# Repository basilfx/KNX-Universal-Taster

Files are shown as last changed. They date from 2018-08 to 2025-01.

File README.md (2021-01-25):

# KNX Universal Taster
DIY universal taster interface for the KNX bus.

## Introduction
This repository contains my designs for creating a custom KNX universal taster
interface (or actor). This is board that can be used for several purposes, but
its main purpose is to convert pulse-based wall switches into KNX-enabled
switches. The boards are designed to be small and should fit wall boxes with a
depth of 50 mm.

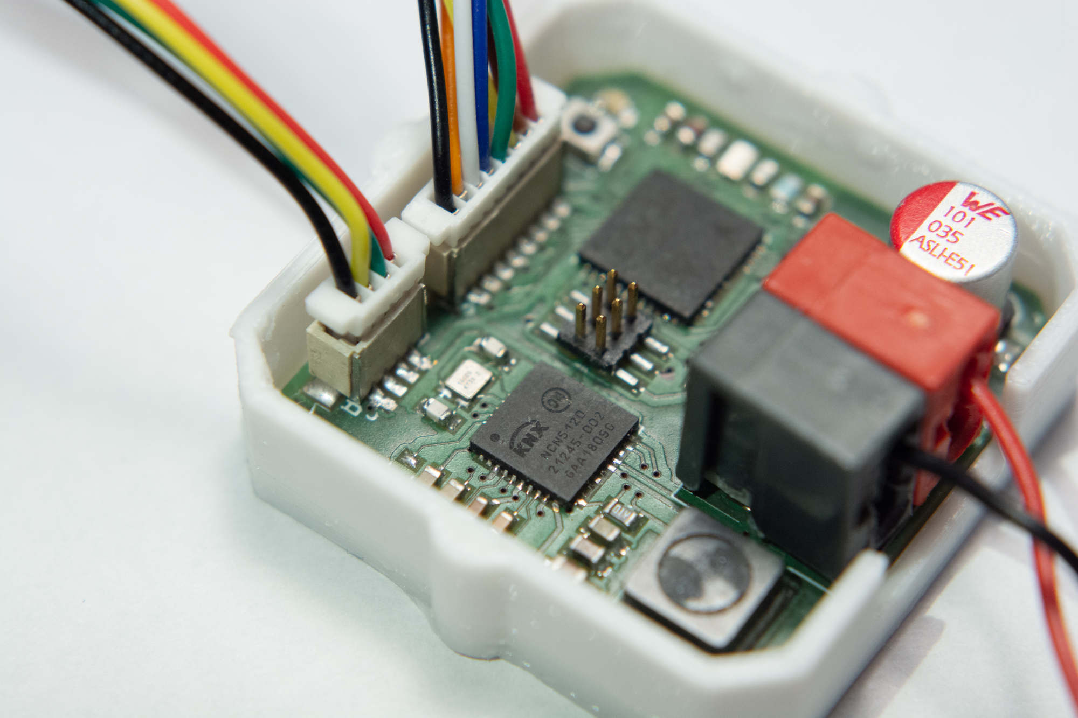
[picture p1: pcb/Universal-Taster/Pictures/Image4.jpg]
Image 4 of complete board.
[](pcb/Universal-Taster/Pictures/Image4.jpg)
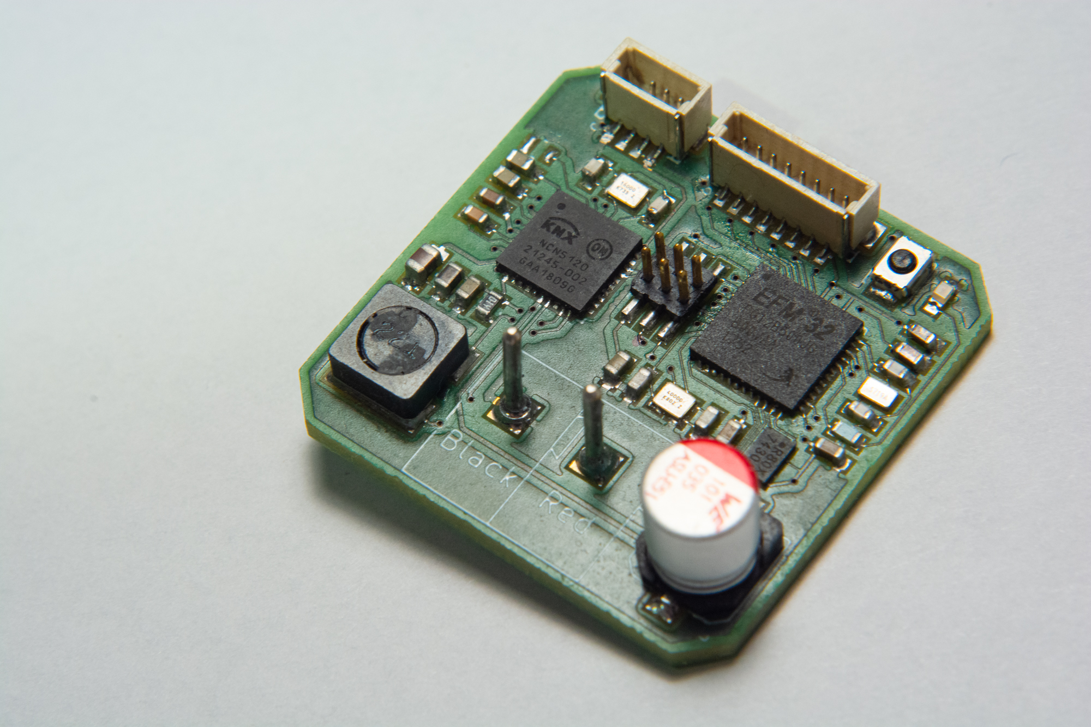
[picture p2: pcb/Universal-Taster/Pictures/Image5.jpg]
Image 5 of complete board.
[](pcb/Universal-Taster/Pictures/Image5.jpg)
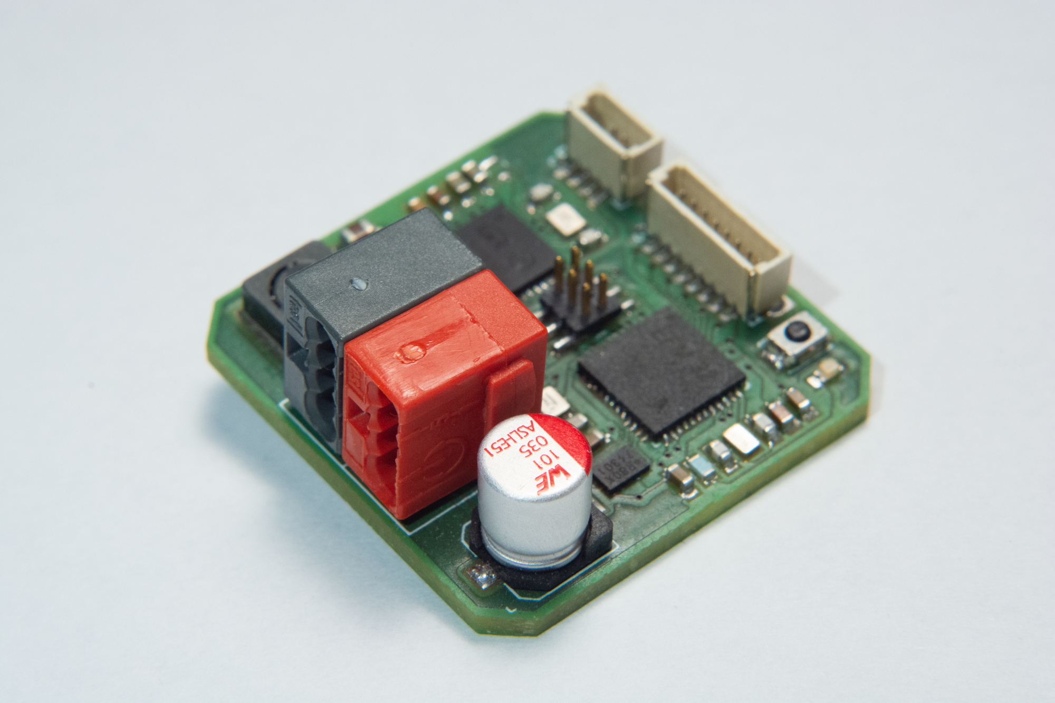
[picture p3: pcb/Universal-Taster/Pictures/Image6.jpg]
Image 6 of complete board.
[](pcb/Universal-Taster/Pictures/Image6.jpg)

I currently have 25 boards installed in my house. As of writing (January 2021),
they have been running for more than two years.

## Features
While commercial alternatives exists, for example the [MDT Universal Interface](https://www.mdt.de/EN_Universal_Interface.html)
or the [ABB Universal Interface](https://new.abb.com/products/GHQ6310070R0111/us-u4-2-universal-interface-4-fold-fm),
I challenged myself to create a version that has more capabilities:

* Smaller.
* Programmable button options, e.g. multiple presses, long(er) presses.
* Support for (environmental) sensors.
* Universal use: data loggers, protocol gateways (Modbus, DSMR).
* Remote configuration via ETS or other software.

## Contents
You can find the following in this repository:

* [3D prints](3d) - Printable parts, such as an enclosure
* [Firmware](firmware) - Firmware files
* [PCB designs](pcb) - KiCad designs for the main PCB and extensions

## Support
You can buy the boards from [Aisler.net](https://aisler.net/p/GGKCSYBF), and
help me to support the development.

## License
The work in this repository is covered by CC BY-NC-SA 4.0. See the `LICENSE.md`
file for more information.

## Disclaimer
Use this project or information at your own risk. I cannot be held responsible
for any injuries or damages.

This page and its content is not affiliated with the KNX Association. Most
certainly, this work is not certified by the KNX Association.

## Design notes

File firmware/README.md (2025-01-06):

# Firmware

## Introduction
This folder contains the firmware releases of the firmware for the Universal
Taster.

This section is work in progress.

## Versions
* [v0.3.0](v0.3.0)

## Features
* Designed to work with the Environmental Sensors board
  * If not used, temperature sensor is connected to the internal temperature
    sensor
* LED + programming button (hold to enable)
* 6 universal inputs
  * Switch mode
  * Intelligent dim: press + hold will dim up, double press + hold will dim
    down
* Temperature and pressure sensor support
* Programmable using ETS5
* Over-the-wire updating (requires separate tool)
* UART shell

## Installation

### From source
The firmware is based on [RIOT-OS](https://github.com/RIOT-OS/RIOT). A
preliminary version of a KNX stack has been developed for this purpose as well.
The firmware source code can be found [here](https://github.com/basilfx/RIOT/tree/feature/knx/examples/gnrc_knx_taster)
(the application will move to another repository in the near future).

To get started, ensure that you have the right tools installed for RIOT-OS.
This includes:

* Git
* GNU Make 4.x
* GNU Arm Embedded Toolchain
* J-Link (flashing)

You will need a J-Link debugger and hook it up to the debug header. The pinout
is as follows (from above, KNX connector on bottom side):

* GND - RESET - 3V3
* SWO - SWDCLK - SWDIO

While not mandatory, the back side contains four pads for a UART (from above,
KNX connector on bottom side):

* GND
* RX
* TX
* 3V3

Start by cloning the repository. Then navigate to the `examples/gnrc_knx_taster`
folder, and read the `README.md` file carefully.

Once you meet all requirements, run `BOARD=basilfx-taster make` to compile the
firmware. To flash it, run `BOARD=basilfx-taster make flash`.

The firmware now be running.

### Precompiled version
You need a J-Link debugger for flashing the firmware. See the above section on
how to connect it.

If the debugger is working, you can run `JLinkExe` to start the programmer.
Follow the on-screen instructions (make sure to select SWD instead of JTAG) to
connect the board.

Once connected, run `loadbin gnrc_knx_taster_slot0-extended.bin 0x0` to flash
the firmware. The firmware now be running.

## Configure using ETS5
A `*.knxprod` file is included, which can be imported in the KNX product
catalog. This file is created using tools listed [here](https://github.com/basilfx/SignKnxProd).

The product will be added under the manufacturer 'Not Assigned'.

Note: in some cases, ETS5 may throw exceptions while importing this product
definition. Sometimes it may help to remove the old definitions from the
catalog, clean-up the product store (Diagnostics -> Troubleshooting), restart
ETS5 and import again.

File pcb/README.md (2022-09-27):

# Printed Circuit Board

## Contents
Several printed circuit boards have been designed for this project.

### Core
* [Universal-Taster](Universal-Taster) - The main board.

### Extension modules
* [Environmental-Sensors](Extensions/Environmental-Sensors) - Environmental
  sensor board that fits inside a Busch-Jaeger switch.
* [DSMR-Connector](Extensions/DSMR-Connector) - Opto-isolated converter to the
  P1 port of Dutch Smart Energy Meter (DSMR 5.0).
* [RS485-Connector](Extensions/RS485-Connector) - Opto-isolated RS485
  converter.

### Testing
* [Interface-Tester](Interface-Tester) - Testing board to test and evaluate the
  main board.

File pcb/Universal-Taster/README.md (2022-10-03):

# Universal Taster

## Features
* ARM Cortex M4 CPU with 1 MiB of flash and 256 KiB of RAM
* Compatible with OnSemi NCN5120 and NCN5121
* 8 Mbit SPI NOR flash
* 6 universal GPIO pins
* 2 pins for I2C
* 2 RX/TX pins (without header)
* 30x30x15 mm footprint (including connector)

## Pictures
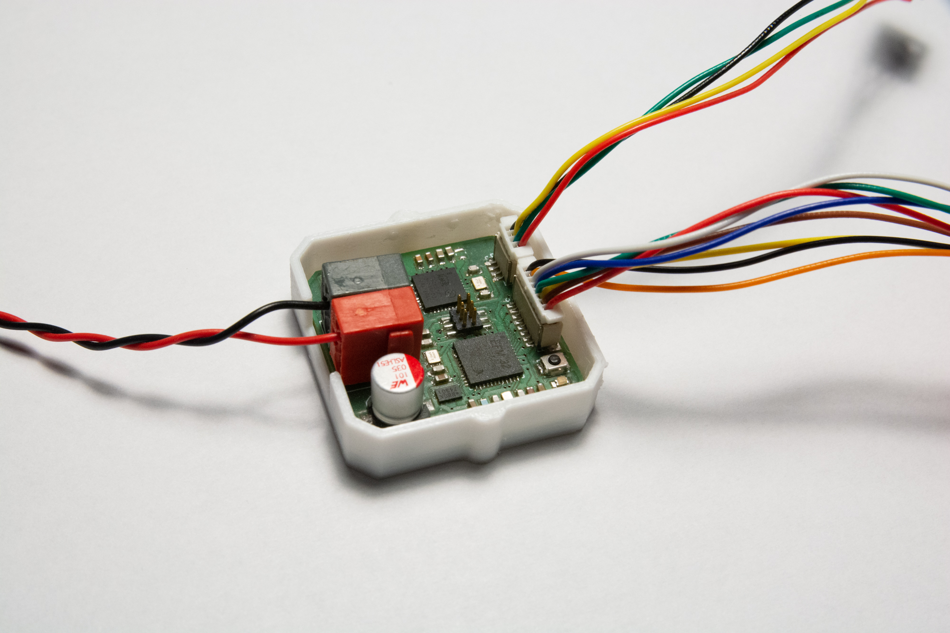
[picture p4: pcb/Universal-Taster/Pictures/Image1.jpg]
Image 1 of complete board.
[](Pictures/Image1.jpg)
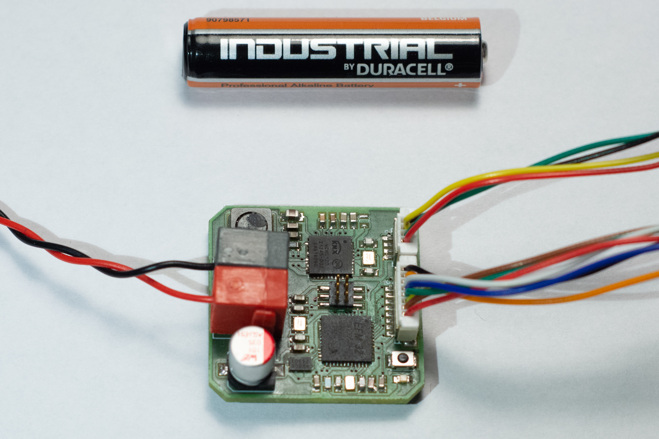
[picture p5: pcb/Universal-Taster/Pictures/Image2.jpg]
Image 2 of complete board.
[](Pictures/Image2.jpg)
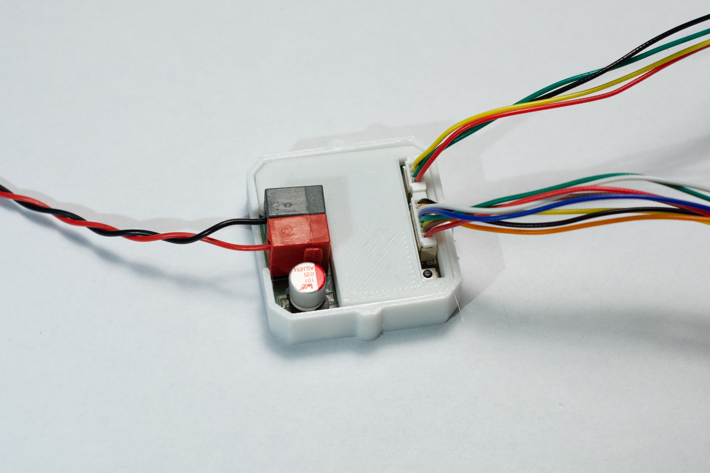
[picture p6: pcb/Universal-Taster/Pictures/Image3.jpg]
Image 3 of complete board.
[](Pictures/Image3.jpg)
[Image 4 of complete board.](Pictures/Image4.jpg)
[Image 5 of complete board.](Pictures/Image5.jpg)
[Image 6 of complete board.](Pictures/Image6.jpg)

## Board
Top layer
Bottom layer

## Schema
You can find the schema [here](Universal-Taster.pdf).

## Compatibility
This board is compatible with the [OnSemi NCN5121](http://www.onsemi.com/pub/Collateral/NCN5121-D.PDF)
or the [OnSemi NCN5120](http://www.onsemi.com/pub/Collateral/NCN5120-D.PDF).

## BoM
The (interactive) BoM can be found [here](https://basilfx.github.io/KNX-Universal-Taster/pcb/Universal-Taster/BoM/ibom.html).

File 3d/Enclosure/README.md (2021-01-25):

# Enclosure

## Introduction
Simple enclosure for the Universal Taster. While not perfect, it will prevent
shorts between the board and other external components.

## Print settings
Print with PETG at 0.2 mm layer height with 100% infill.

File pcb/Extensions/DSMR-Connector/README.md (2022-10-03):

# DSMR-Connector

## Introduction
This board converts the P1 port found on Dutch Smart Energy Meters to UART,
opto-isolated from the Taster module. You can find more information in the
[P1 Companion Standard](https://www.netbeheernederland.nl/_upload/Files/Slimme_meter_15_a727fce1f1.pdf).

This board is only compatible with DSMR 5.0, since that version is using two
additional pins (therefore RJ-12 instead of RJ-11) to supply the bidirectional
optocoupler.

## Board
Top layer
Bottom layer

## Schema
You can find the schema [here](DSMR-Connector.pdf).

## BoM
The (interactive) BoM can be found [here](https://basilfx.github.io/KNX-Universal-Taster/pcb/Extensions/DSMR-Connector/BoM/ibom.html).

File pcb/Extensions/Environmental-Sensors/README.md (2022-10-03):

# Environmental-Sensors

## Board
Top layer
Bottom layer

## Schema
You can find the schema [here](Environmental-Sensors.pdf).

## BoM
The (interactive) BoM can be found [here](https://basilfx.github.io/KNX-Universal-Taster/pcb/Extensions/Environmental-Sensors/BoM/ibom.html).

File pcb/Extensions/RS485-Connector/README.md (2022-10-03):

# RS485-Connector

## Introduction
Isolated RS485 converter, full and half duplex.

## Board
Top layer
Bottom layer

## Schema
You can find the schema [here](RS485-Connector.pdf).

## BoM
The (interactive) BoM can be found [here](https://basilfx.gthub.io/KNX-Universal-Taster/pcb/Extensions/RS485-Connector/BoM/ibom.html).

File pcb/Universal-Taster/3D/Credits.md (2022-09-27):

# Credits

## BM04B-SRSS-TB
Downloaded from https://grabcad.com/library/jst-sh-smd-connectors-1

## BM08B-SRSS-TB
Downloaded from https://grabcad.com/library/jst-sh-smd-connectors-1

## SRR5028
Downloaded from https://www.snapeda.com/parts/SRR5028-390Y/Bourns/view-part

## Wago_243-211
Downloaded from https://www.snapeda.com/parts/243-211/Molex/view-part

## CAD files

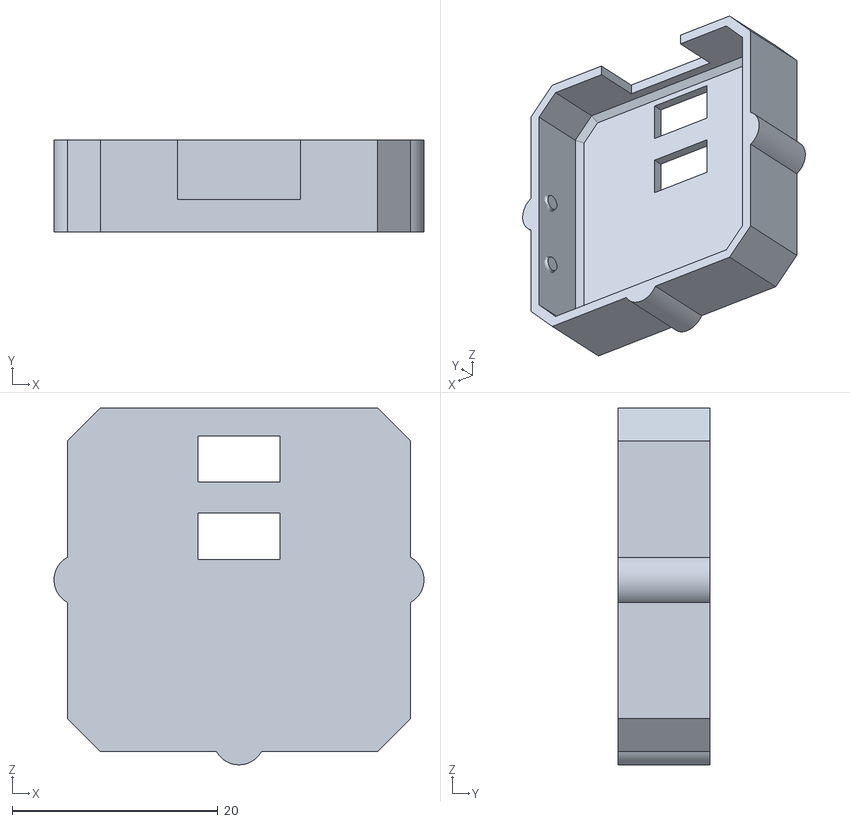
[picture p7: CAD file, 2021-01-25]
3d/Enclosure/Bottom.stl
36.0 x 9.00 x 34.7

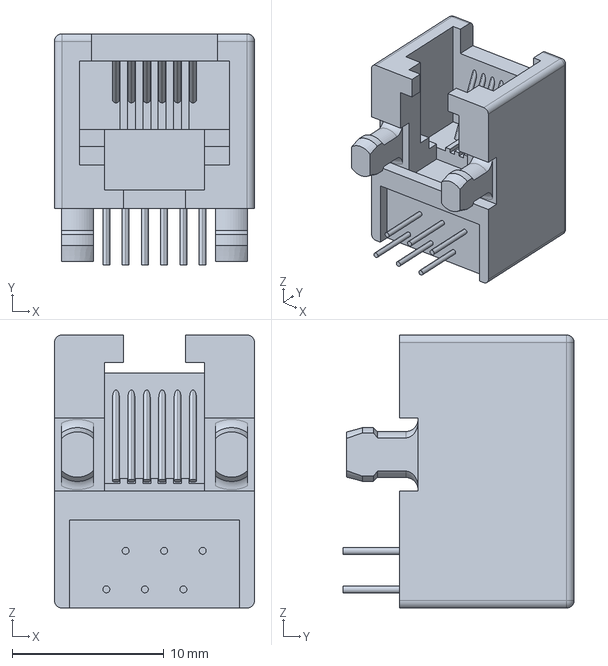
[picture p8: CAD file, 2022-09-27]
pcb/Extensions/DSMR-Connector/3D/Amphenol-54601-906WPLF.step
13.2 x 15.2 x 18.0 mm

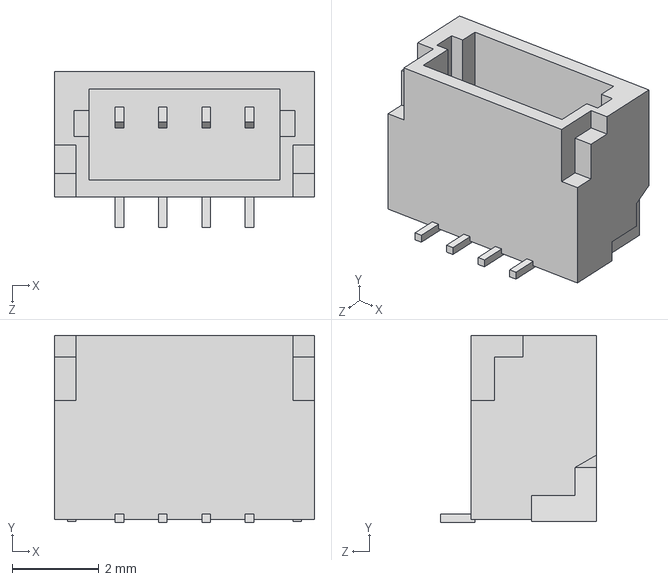
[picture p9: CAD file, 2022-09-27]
pcb/Universal-Taster/3D/BM04B-SRSS-TB.step
6.00 x 4.32 x 3.60 mm

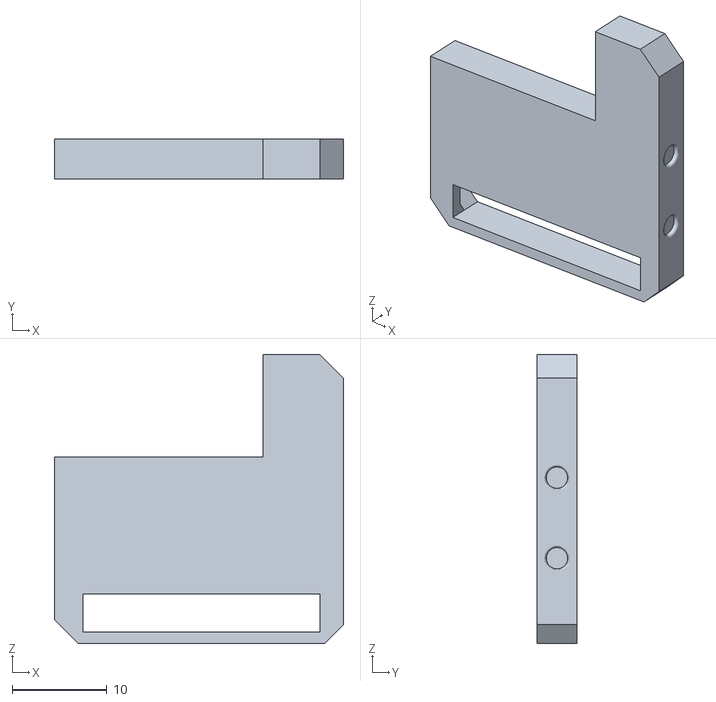
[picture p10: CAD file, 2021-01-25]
3d/Enclosure/Top.stl
30.5 x 4.20 x 30.5

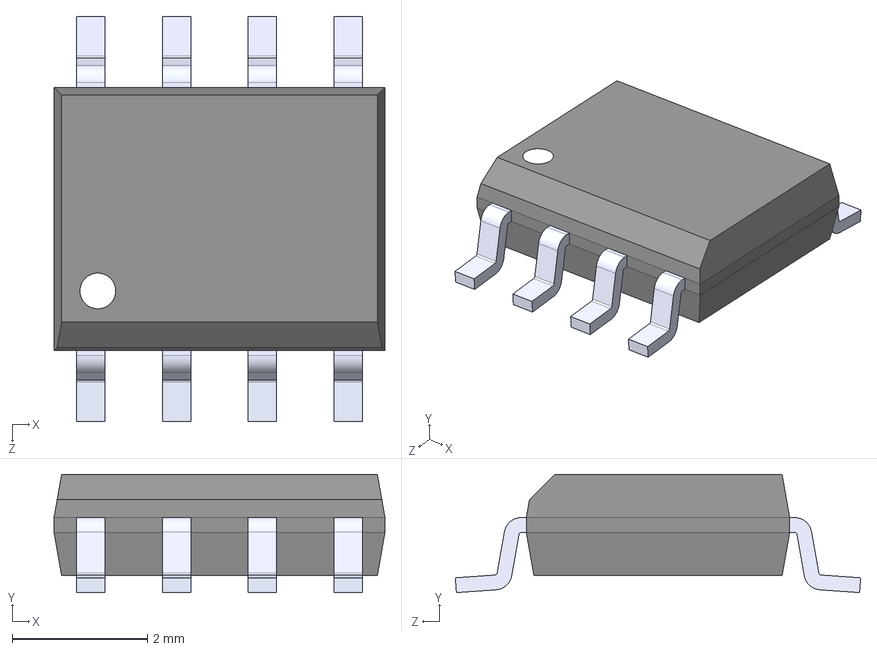
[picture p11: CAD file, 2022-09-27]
pcb/Extensions/DSMR-Connector/3D/FOD8012.step
4.90 x 1.75 x 6.00 mm

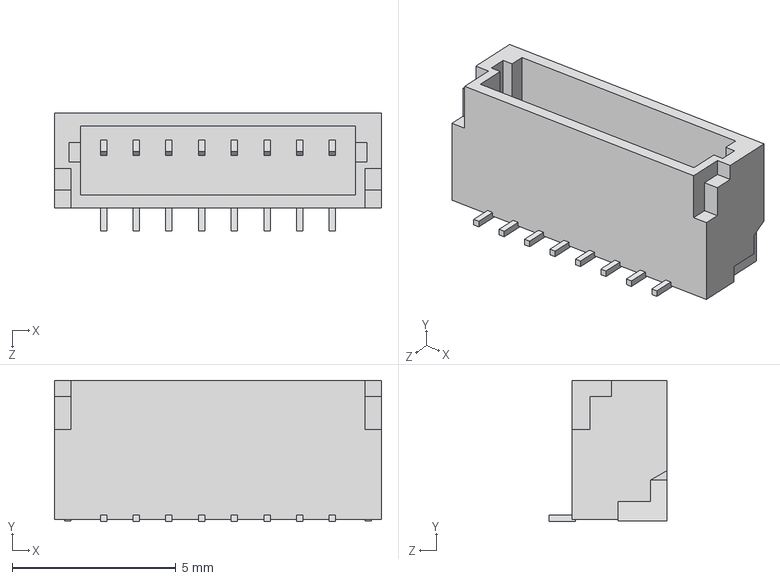
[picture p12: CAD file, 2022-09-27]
pcb/Universal-Taster/3D/BM08B-SRSS-TB.step
10.0 x 4.32 x 3.60 mm

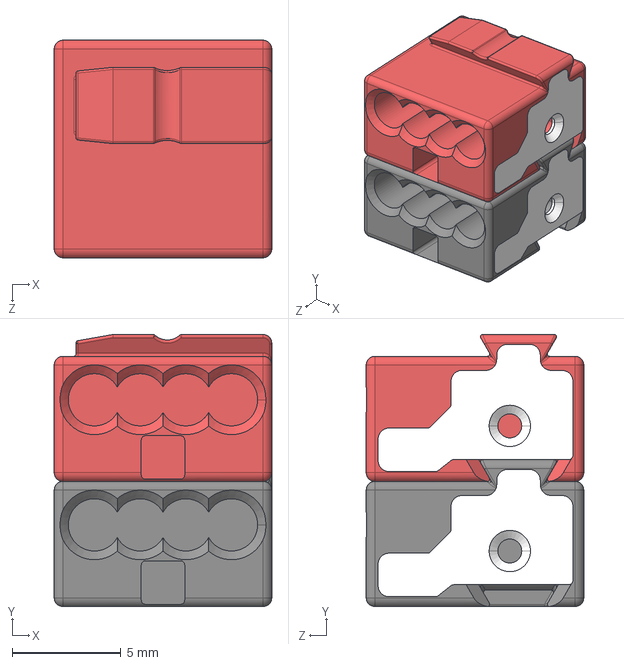
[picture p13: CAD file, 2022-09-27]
pcb/Universal-Taster/3D/Wago_243-211.step
10.0 x 12.5 x 10.0 mm

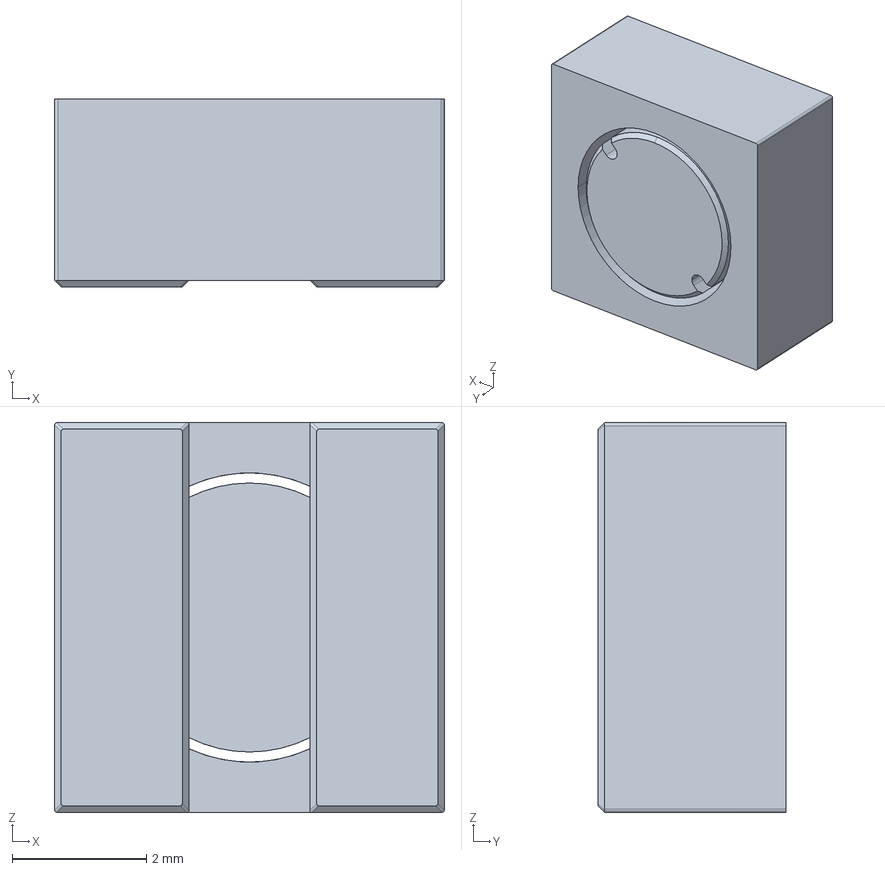
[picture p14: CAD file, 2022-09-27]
pcb/Universal-Taster/3D/SRR5028.step
5.80 x 2.80 x 5.80 mm

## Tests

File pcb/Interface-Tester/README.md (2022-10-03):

# Interface Tester

## Introduction
This is an interface tester for the taster board. It is used for verification
purposes

## Board
Top layer
Bottom layer

## Schema
You can find the schema [here](Interface-Tester.pdf).

## BoM
The (interactive) BoM can be found [here](https://basilfx.github.io/KNX-Universal-Taster/pcb/Interface-Tester/BoM/ibom.html).

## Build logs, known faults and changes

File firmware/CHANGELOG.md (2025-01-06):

# Changelog

## v0.4.0
Released 6 January 2025

Highlights:
* Fixed: delay transceiver initialization until ready
* Added: support for compressed images for over-the-wire updates
* Added: added property to expose OTA version

## v0.3.0
Released 25 January 2021

Highlights:
* Initial version.

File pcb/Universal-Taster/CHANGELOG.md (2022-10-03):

# Changelog

## v1.3.1
Released 03 October 2022

Highlights:
* Fixed: rotation of KNX connector silkscreen.
* Fixed: 3D models not included.

## v1.3.0
Released 28 September 2022

Highlights:
* Changed: migrated schema + PCB to KiCad 6.0.
* Improved: 3D models.
* Fixed: many ERC and DRC errors.

## v1.2.1
Released 15 July 2021

Highlights:
* Improved: clearance between trace and SCL resistor.
* Fixed: several DRC errors.

## v1.2.0
Released 20 August 2018

Highlights:
* Added: Resistor between NCN5120 RESET line and other RESET lines.
* Improved: clearance of KNX connector to ground plane.
* Changed: migrated schema + PCB to KiCad 5.0.
* Changed: smaller pads for optional UART.

## v1.1.0
Released 24 June 2018

Highlights:
* Added: compatibility with NCN5121.
* Added: VCC for RX/TX pins on the bottom.
* Fixed: missing pins on the flash chip.
* Fixed: reset line.

## v1.0.0
Released 11 June 2018

Highlights:
* Initial version.

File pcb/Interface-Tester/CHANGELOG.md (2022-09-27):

# Changelog

## v1.3.0
Released 28 September 2022

Highlights:
* Changed: migrated schema + PCB to KiCad 6.0.
* Fixed: several ERC and DRC errors.

## v1.1.0
Released 20 August 2018

Highlight:
* Changed: migrated schema + PCB to KiCad 5.0.

## v1.0.0
Released 11 June 2018

Highlights:
* Initial version.

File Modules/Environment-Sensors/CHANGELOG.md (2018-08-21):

# Changelog

## v1.1.0
Released 21 August 2018

Highlights:
* Changed: migrated schema + PCB to KiCad 5.0.
* Improved: board layout and dimensions.
* Added: top notch to fit better inside switch.

## v1.0.0
Released 11 June 2018

Highlights:
* Initial version.

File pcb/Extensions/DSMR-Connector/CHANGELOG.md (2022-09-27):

# Changelog

## v1.2.0
Released 28 September 2022

Highlights:
* Changed: migrated schema + PCB to KiCad 6.0.
* Improved: 3D models.
* Fixed: several ERC and DRC errors.

## v1.1.0
Released 15 July 2021

Highlights:
* Fixed: add missing pull-up on TXA line.
* Improved: add inverter on TX line.

## v1.0.0
Released 22 August 2018

Highlights:
* Initial version.

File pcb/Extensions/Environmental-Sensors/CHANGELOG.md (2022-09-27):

# Changelog

## v1.3.0
Released 28 September 2022

Highlights:
* Changed: migrated schema + PCB to KiCad 6.0.
* Fixed: several ERC and DRC errors.

## v1.2.0
Released 22 August 2018

Highlights:
* Added: 4.7 µF across VDD and GND.
* Changed: made thermal pad of CCS811 bit smaller for increased clearance.

## v1.1.0
Released 21 August 2018

Highlights:
* Changed: migrated schema + PCB to KiCad 5.0.
* Improved: board layout and dimensions.
* Added: top notch to fit better inside switch.

## v1.0.0
Released 11 June 2018

Highlights:
* Initial version.

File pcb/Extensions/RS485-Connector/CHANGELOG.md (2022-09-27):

# Changelog

## v1.1.0
Released 28 September 2022

Highlights:
* Changed: migrated schema + PCB to KiCad 6.0.
* Fixed: several ERC and DRC errors.

## v1.0.0
Released 26 August 2018

Highlights:
* Initial version.

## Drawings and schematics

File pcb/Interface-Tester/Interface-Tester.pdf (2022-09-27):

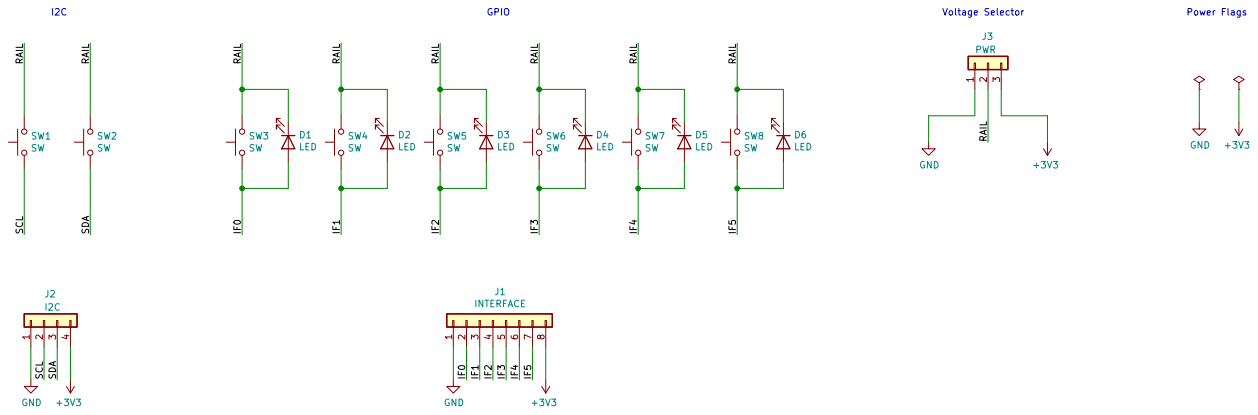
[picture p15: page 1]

File: Interface-Tester.kicad_sch Sheet: /
Id: 1/1 Title:

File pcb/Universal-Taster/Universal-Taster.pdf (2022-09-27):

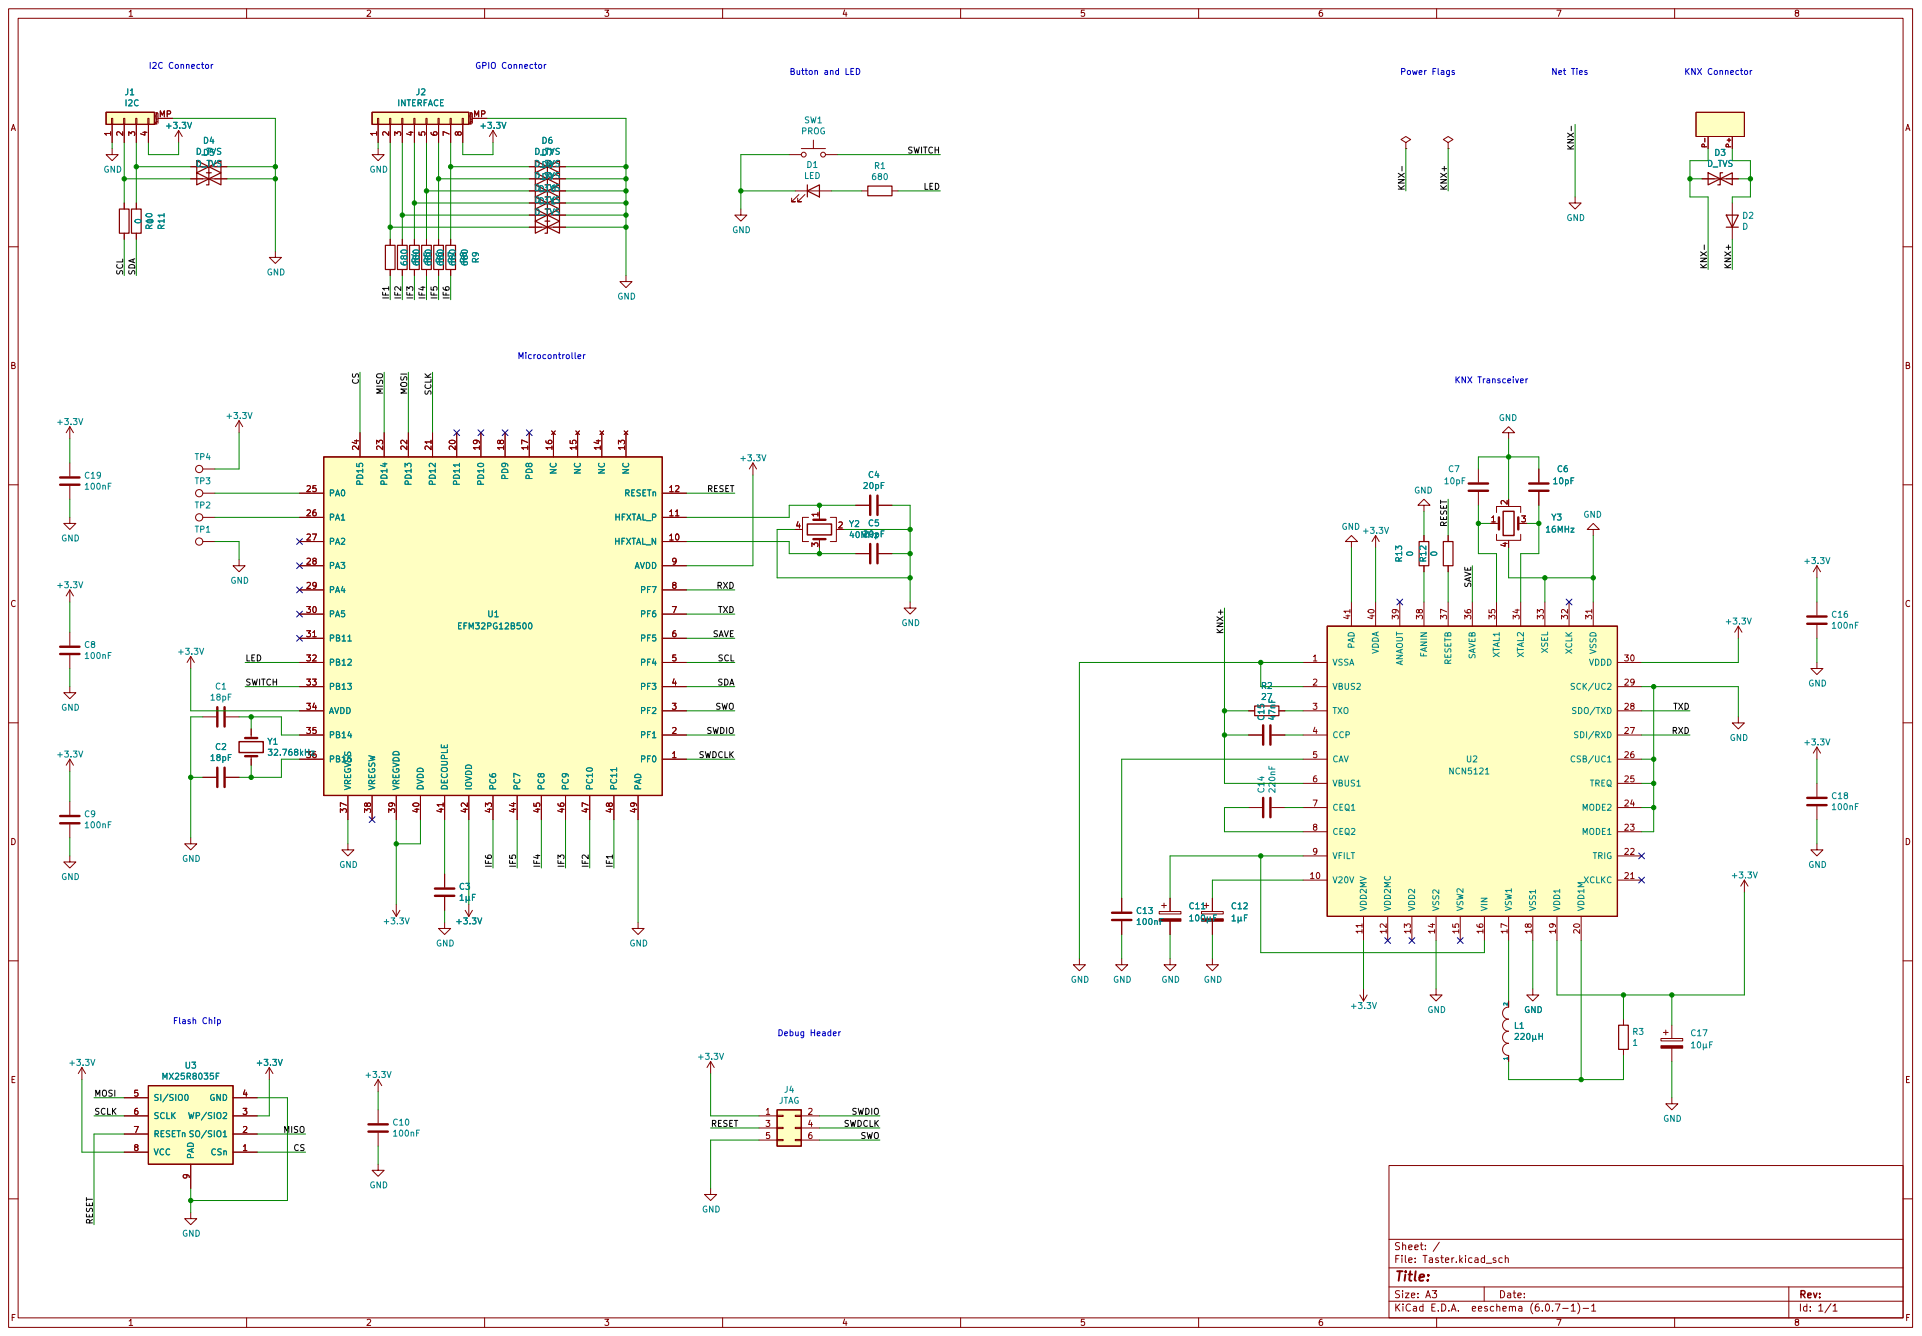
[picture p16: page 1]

D10 D_TVS Mounting 1 LED GND Mounting 1

8 MP D10 D_TVS D11 D_TVS 680 R5 680 R6 680 R7 680 R8 680 R9 U1 EFM32PG12B500 PF0 1 HFXTAL_N 10 HFXTAL_P 11 RESETn 12 NC 13 NC 14 NC 15 NC 16 PD8 17 PD9 18 PD10 19 PF1 2 PD11 20 PD12 21 PD13 22 PD14 23 PD15 24 PA0 25 PA1 26 PA2 27 PA3 28 PA4 29 PF2 3 PA5 30 PB11 31 PB12 32 PB13 33 AVDD 34 PB14 35 PB15 36 VREGVSS 37 VREGSW 38 VREGVDD 39 PF3 4 DVDD 40 DECOUPLE 41 IOVDD 42 PC6 43 PC7 44 PC8 45 PC9 46 PC10 47 PC11 48 PAD 49 PF4 5 PF5 6 PF6 7 PF7 8 AVDD 9 C2

+3.3V +3.3V 680 R4 D6 D_TVS D8 D_TVS 680 R4 D8 D_TVS D6 D_TVS D7 D_TVS D9 D_TVS

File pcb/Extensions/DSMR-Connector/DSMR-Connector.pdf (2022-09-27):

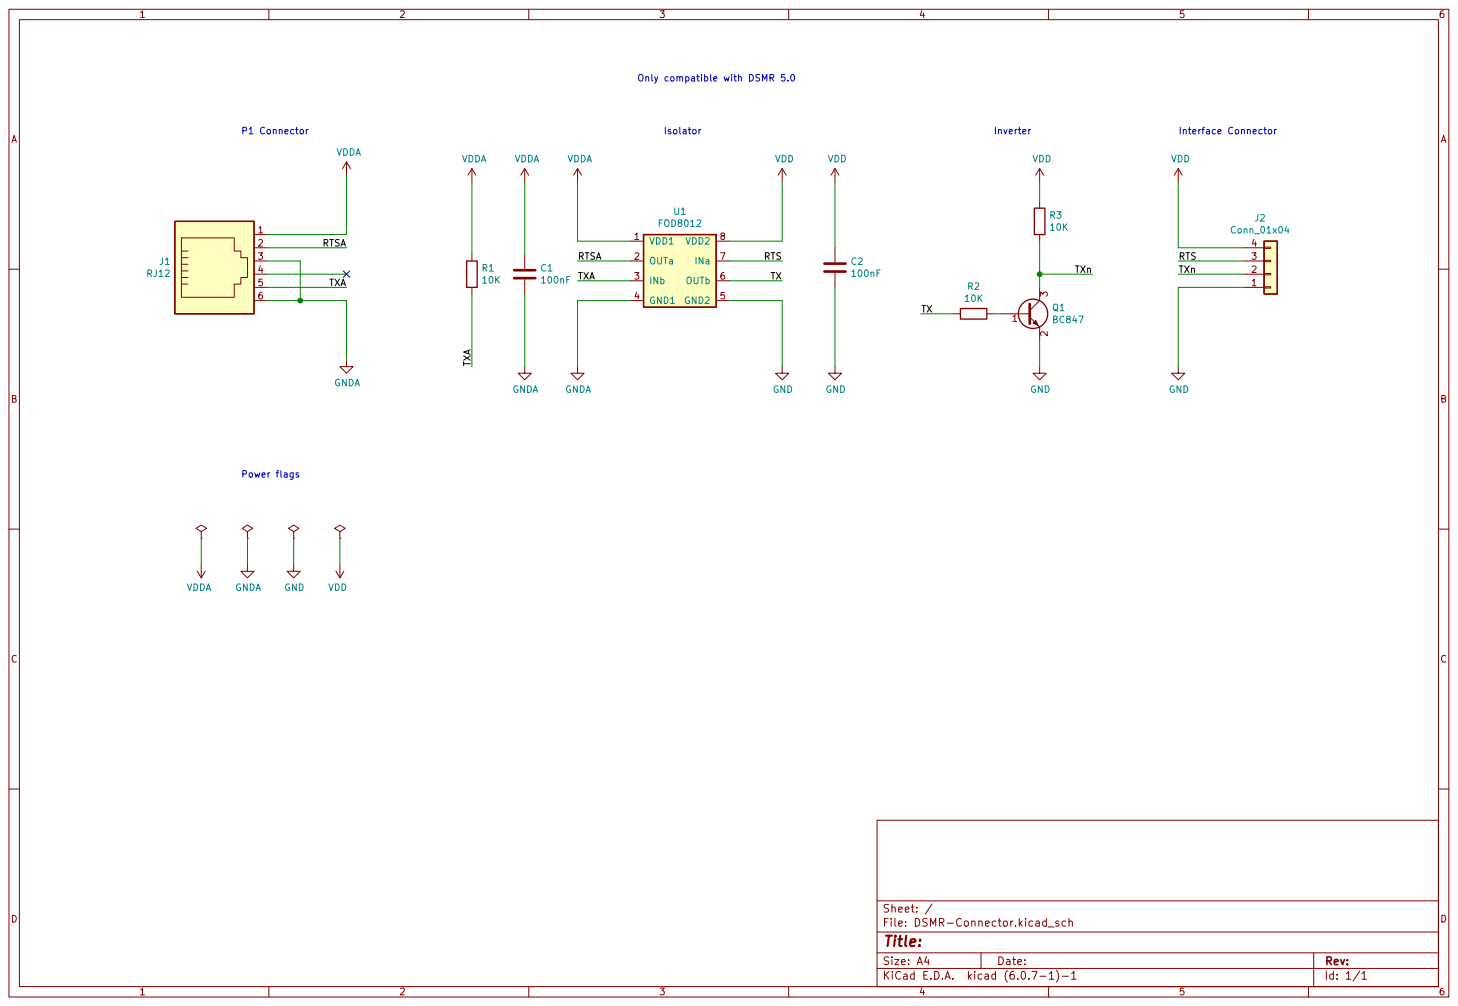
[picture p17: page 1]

File: DSMR-Connector.kicad_sch Sheet: /
Id: 1/1 Title:

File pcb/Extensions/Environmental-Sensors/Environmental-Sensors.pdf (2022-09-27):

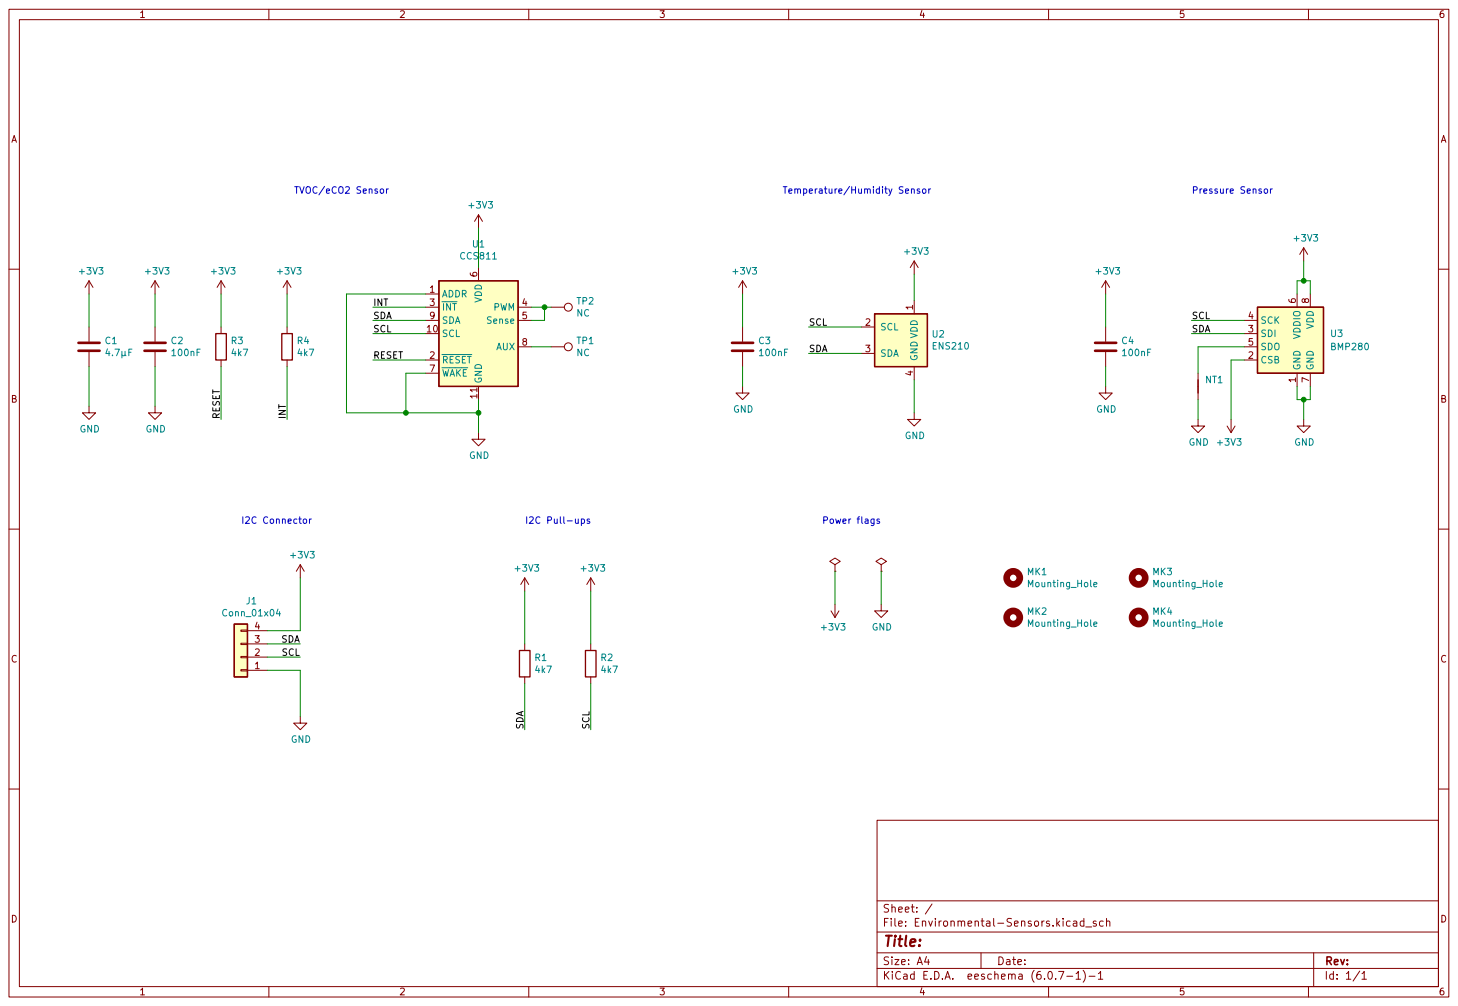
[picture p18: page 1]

1 CSB 2 SDI 3 SCK 4 SDO 5 VDDIO

File: Environmental-Sensors.kicad_sch Sheet: /
Id: 1/1 Title:

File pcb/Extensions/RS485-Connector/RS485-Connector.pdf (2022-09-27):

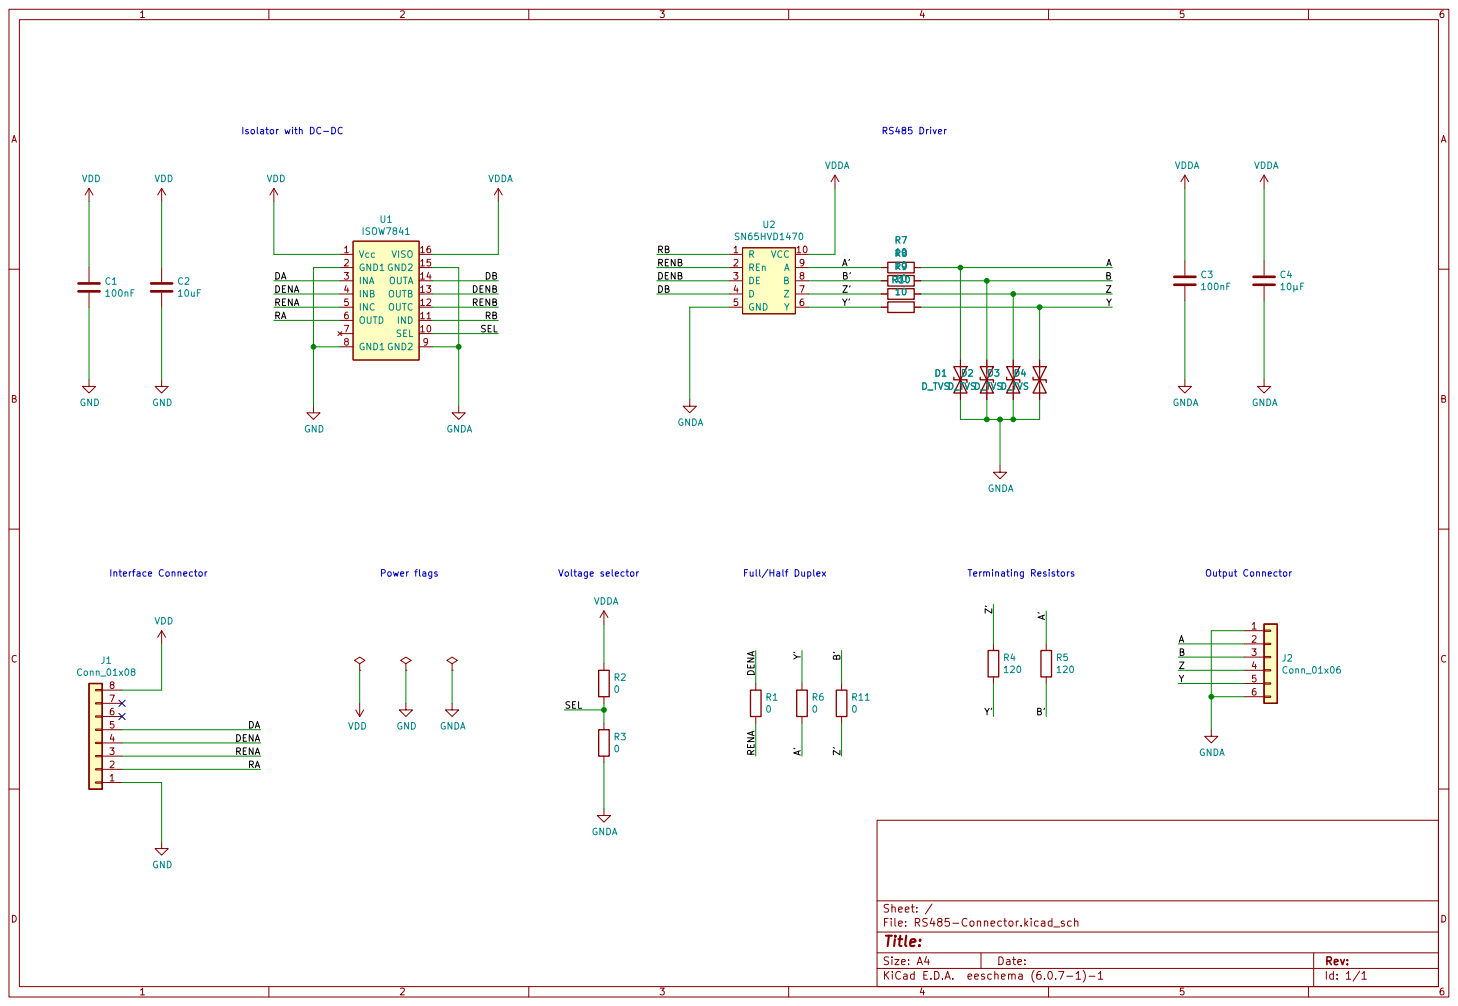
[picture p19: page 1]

Isolator with DC-DC

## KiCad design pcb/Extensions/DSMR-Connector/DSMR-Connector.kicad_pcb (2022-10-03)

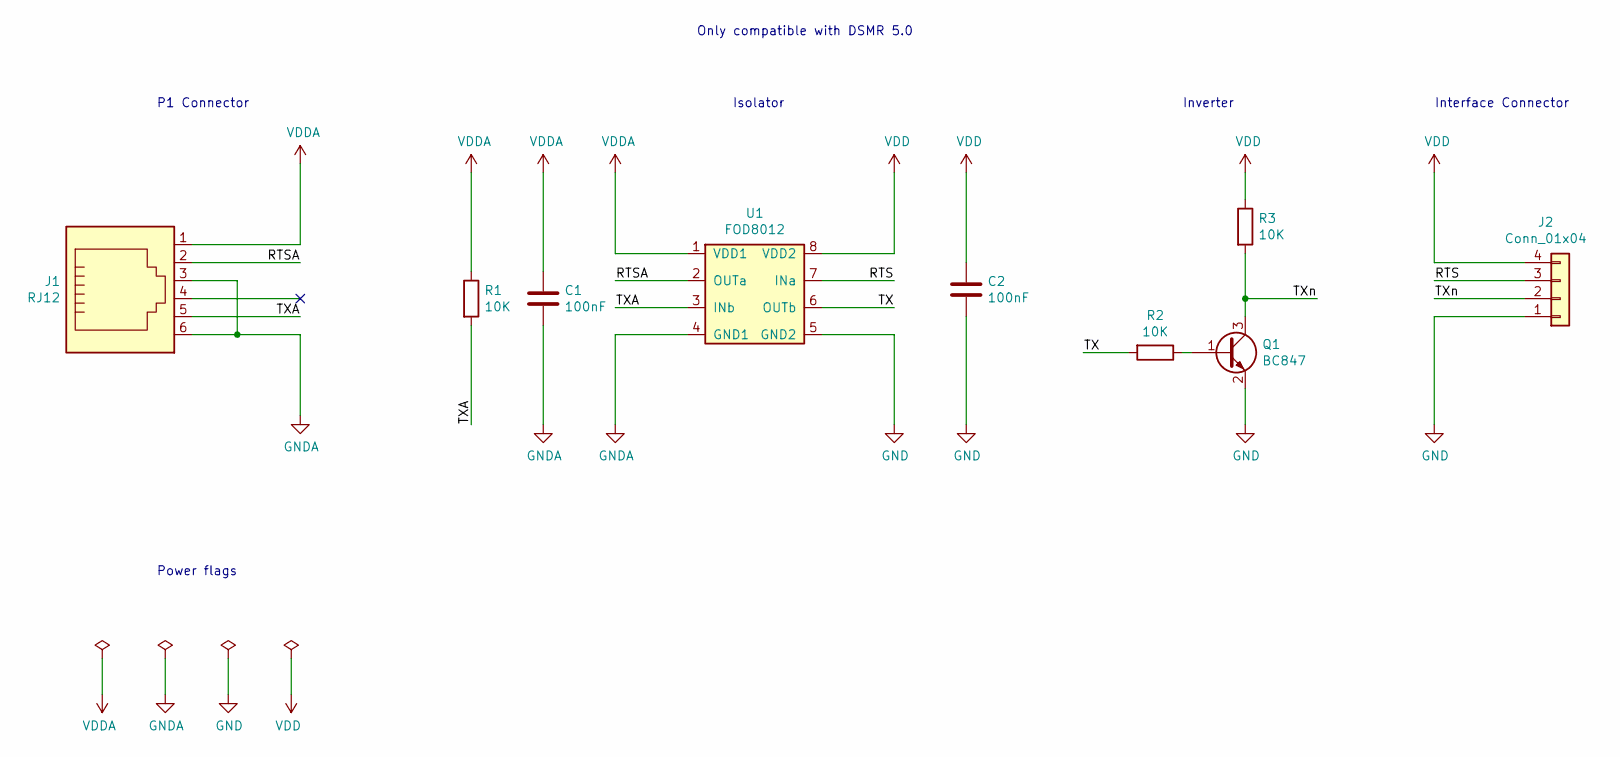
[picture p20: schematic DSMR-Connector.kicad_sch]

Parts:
C1, C2: 100nF; C_0603_1608Metric
J1: RJ12; RJ12_Amphenol_54601
J2: Conn_01x04; PinHeader_1x04_P1.27mm_Vertical
Q1: BC847; SOT-23
R1, R2, R3: 10K; R_0603_1608Metric
U1: FOD8012; SOIC-8-N

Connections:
/RTS: J2.3, U1.7 (INa)
/RTSA: J1.2, U1.2 (OUTa)
/TX: R2.2, U1.6 (OUTb)
/TXA: J1.5, R1.2, U1.3 (INb)
/TXn: J2.2, Q1.3 (C), R3.2
GND: C2.2, J2.1, Q1.2 (E), U1.5 (GND2)
GNDA: C1.2, J1.3, J1.6, U1.4 (GND1)
unnamed: Q1.1 (B), R2.1
VDD: C2.1, J2.4, R3.1, U1.8 (VDD2)
VDDA: C1.1, J1.1, R1.1, U1.1 (VDD1)

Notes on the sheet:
Inverter
Isolator
Power flags
P1 Connector
Only compatible with DSMR 5.0
Interface Connector

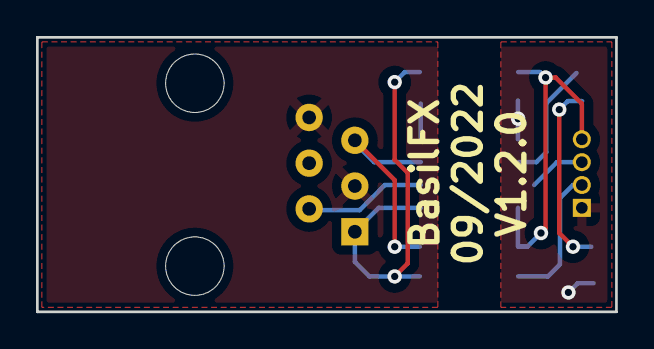
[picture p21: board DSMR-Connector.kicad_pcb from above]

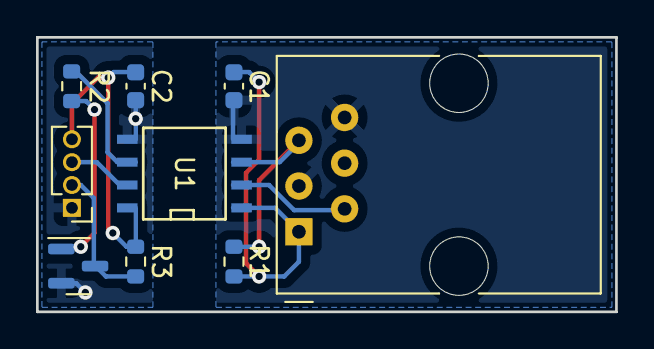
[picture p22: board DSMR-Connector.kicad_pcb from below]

Board: 2 copper layers, 32.2 x 15.2 mm, 9 parts (9 on the bottom side), 10 nets.

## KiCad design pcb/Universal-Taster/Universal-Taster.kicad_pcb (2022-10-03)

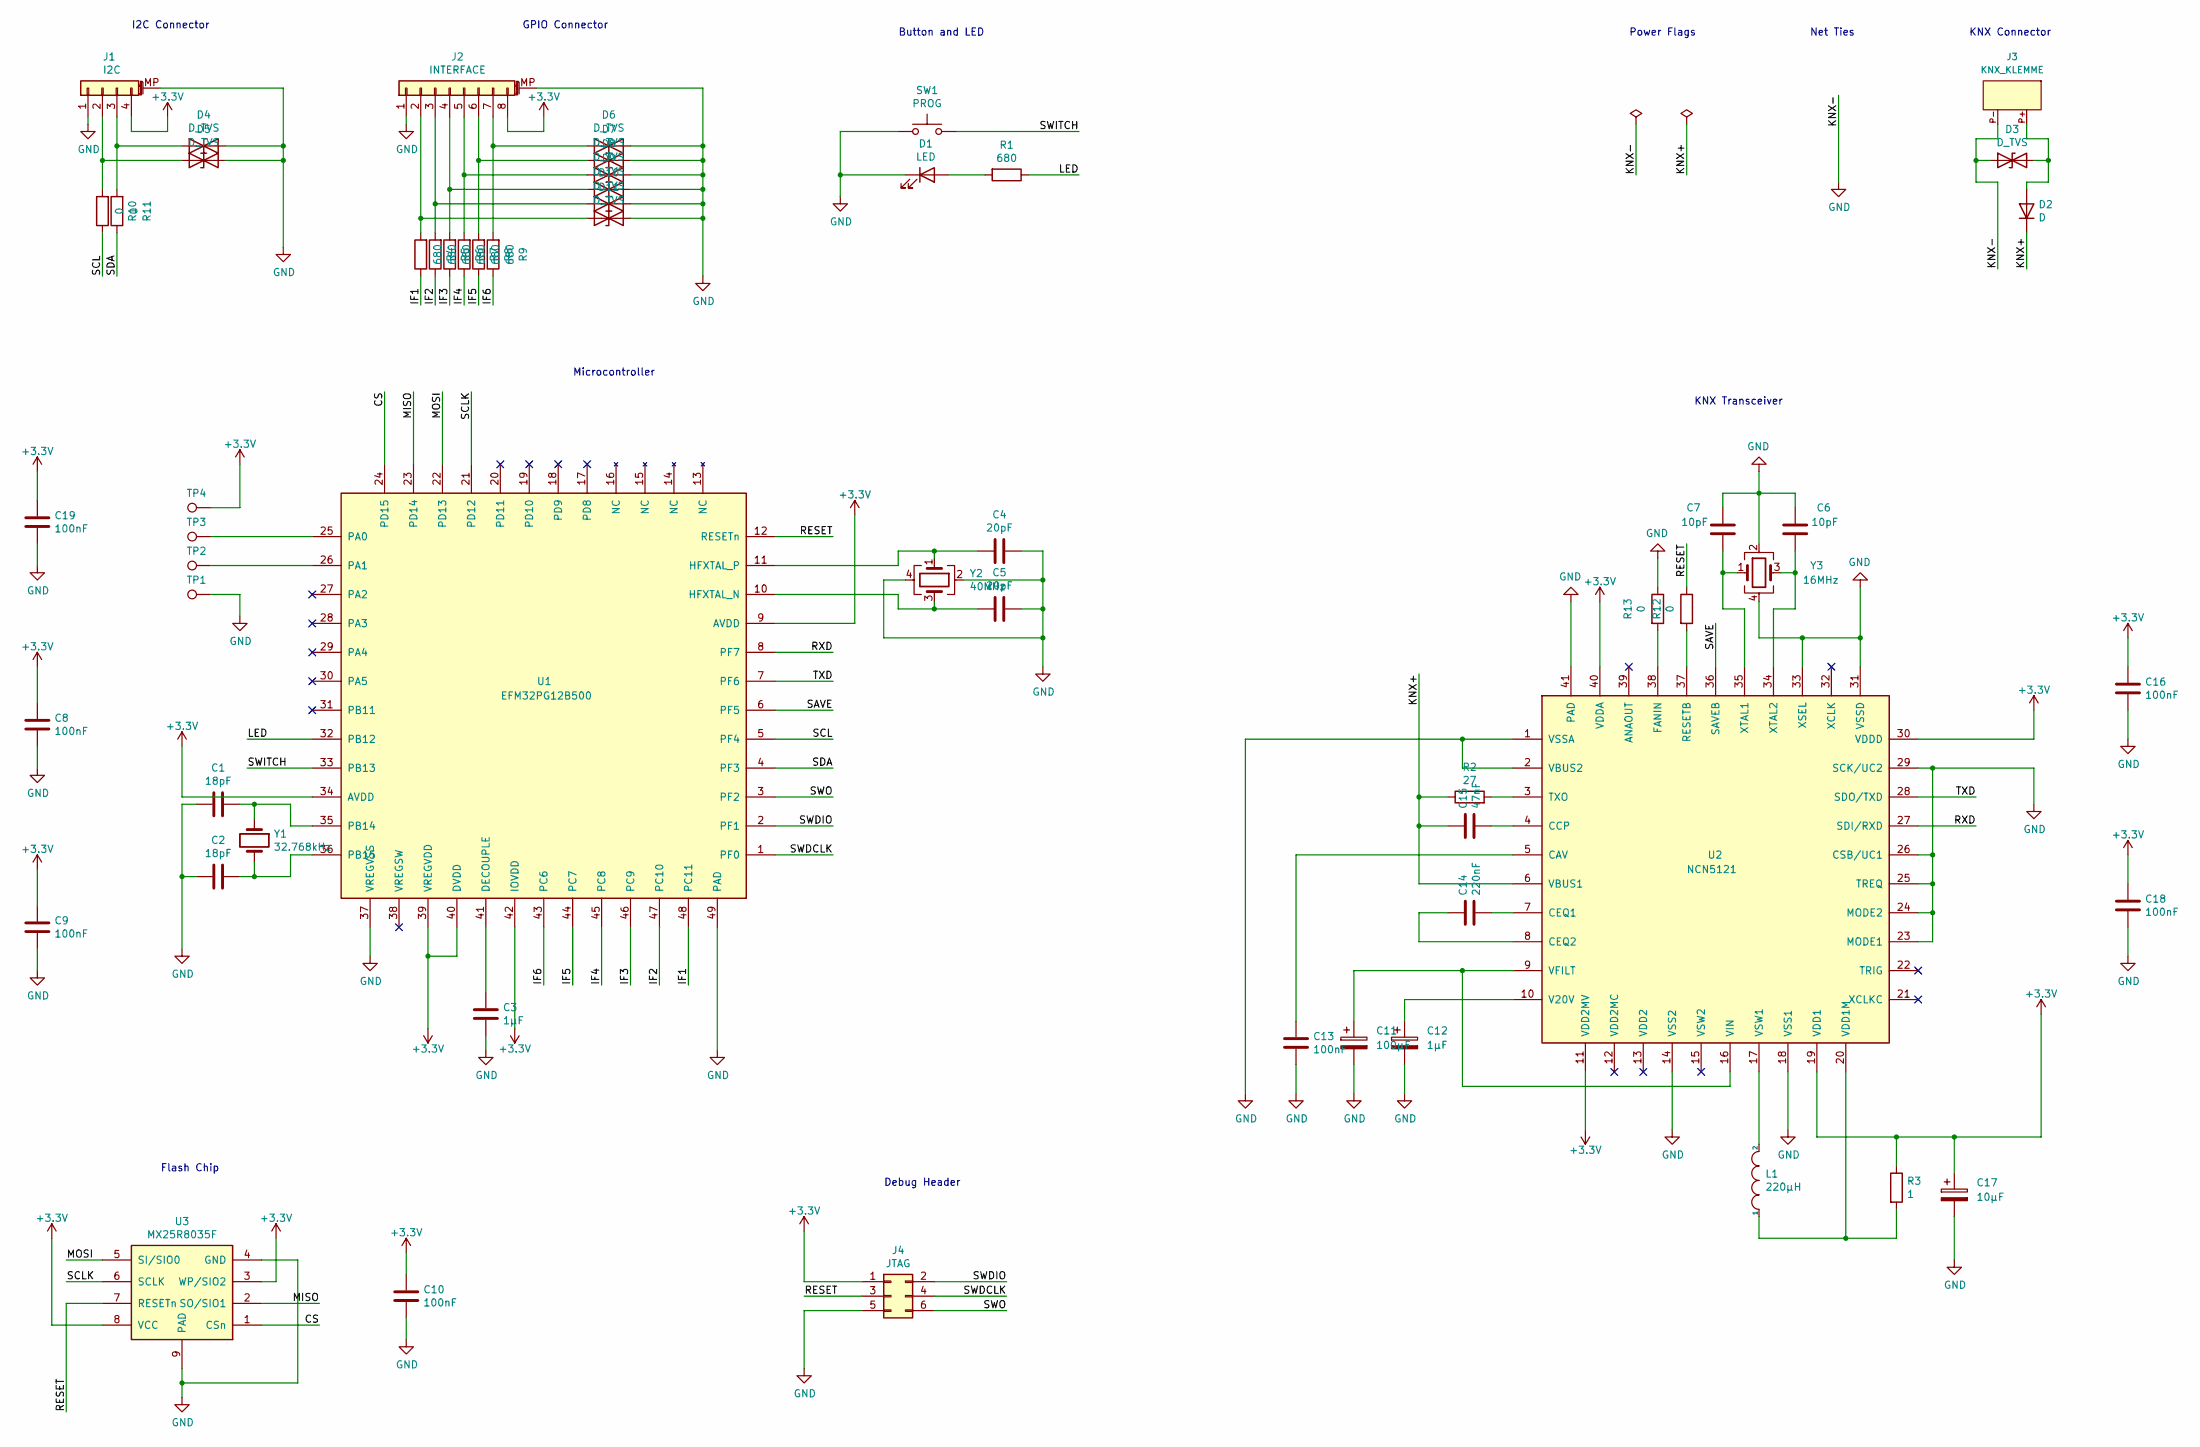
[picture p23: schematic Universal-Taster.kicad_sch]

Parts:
C1, C2: 18pF; C_0603_1608Metric
C3: 1µF; C_0603_1608Metric
C4, C5: 20pF; C_0603_1608Metric
C6, C7: 10pF; C_0603_1608Metric
C8, C9, C10, C13, C16, C18, C19: 100nF; C_0603_1608Metric
C11: 100µF; CP_Elec_6.3x7.7
C12: 1µF; C_0805_2012Metric
C14: 220nF; C_0603_1608Metric
C15: 47nF; C_0603_1608Metric
C17: 10µF; C_0603_1608Metric
D1: LED; LED_0603_1608Metric
D2: D; D_SMB
D3: D_TVS; D_SMB
D4, D5, D6, D7, D8, D9, D10, D11: D_TVS; D_0603_1608Metric
J1: I2C; JST_SH_BM04B-SRSS-TB_1x04-1MP_P1.00mm_Vertical
J2: INTERFACE; JST_SH_BM08B-SRSS-TB_1x08-1MP_P1.00mm_Vertical
J3: KNX_KLEMME
J4: JTAG; PinHeader_2x03_P1.27mm_Vertical_SMD
L1: 220µH; L_Bourns-SRR5028
R1, R4, R5, R6, R7, R8, R9: 680; R_0603_1608Metric
R2: 27; R_2512_6332Metric
R3: 1; R_0603_1608Metric
R10, R11, R12, R13: 0; R_0603_1608Metric
SW1: PROG; SW_SPST_B3U-1000P
TP1, TP2, TP3, TP4: Test_Point; TestPoint_Pad_D1.0mm
U1: EFM32PG12B500; Infineon_MLPQ-48-1EP_7x7mm_P0.5mm_Pad5.15x5.15mm
U2: NCN5121; QFN-40-1EP_6x6mm_P0.5mm_EP4.6x4.6mm
U3: MX25R8035F; USON-8_2x3mm_P0.5mm
Y1: 32.768kHz; Crystal_SMD_2012-2Pin_2.0x1.2mm
Y2: 40MHz; Crystal_SMD_2016-4Pin_2.0x1.6mm
Y3: 16MHz; Crystal_SMD_2016-4Pin_2.0x1.6mm

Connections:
+3.3V: C8.1, C9.1, C10.1, C16.1, C17.1, C18.1, C19.1, J1.4, J2.8, J4.1, R3.1, TP4.1, U1.9 (AVDD), U1.34 (AVDD), U1.39 (VREGVDD), U1.40 (DVDD), U1.42 (IOVDD), U2.11 (VDD2MV), U2.19 (VDD1), U2.30 (VDDD), U2.40 (VDDA), U3.3 (WP/SIO2), U3.8 (VCC)
/CS: U1.24 (PD15), U3.1 (CSn)
/IF1: R4.1, U1.48 (PC11)
/IF2: R5.1, U1.47 (PC10)
/IF3: R6.1, U1.46 (PC9)
/IF4: R7.1, U1.45 (PC8)
/IF5: R8.1, U1.44 (PC7)
/IF6: R9.1, U1.43 (PC6)
/KNX+: C15.1, D2.1 (K), R2.1, U2.6 (VBUS1)
/LED: R1.1, U1.32 (PB12)
/MISO: U1.23 (PD14), U3.2 (SO/SIO1)
/MOSI: U1.22 (PD13), U3.5 (SI/SIO0)
/RESET: J4.3, R12.1, U1.12 (RESETn), U3.7 (RESETn)
/RXD: U1.8 (PF7), U2.27 (SDI/RXD)
/SAVE: U1.6 (PF5), U2.36 (SAVEB)
/SCL: R10.1, U1.5 (PF4)
/SCLK: U1.21 (PD12), U3.6 (SCLK)
/SDA: R11.1, U1.4 (PF3)
/SWDCLK: J4.4, U1.1 (PF0)
/SWDIO: J4.2, U1.2 (PF1)
/SWITCH: SW1.2, U1.33 (PB13)
/SWO: J4.6, U1.3 (PF2)
/TXD: U1.7 (PF6), U2.28 (SDO/TXD)
GND: C1.1, C2.1, C3.2, C4.2, C5.2, C6.2, C7.2, C8.2, C9.2, C10.2, C11.2, C12.2, C13.2, C16.2, C17.2, C18.2, C19.2, D1.1 (K), D3.1 (A1), D4.2 (A2), D5.2 (A2), D6.2 (A2), D7.2 (A2), D8.2 (A2), D9.2 (A2), D10.2 (A2), D11.2 (A2), J1.1, J1.MP (MountPin), J2.1, J2.MP (MountPin), J3.P- (-), J4.5, R13.1, SW1.1, TP1.1, U1.37 (VREGVSS), U1.49 (PAD), U2.1 (VSSA), U2.2 (VBUS2), U2.14 (VSS2), U2.18 (VSS1), U2.23 (MODE1), U2.24 (MODE2), U2.25 (TREQ), U2.26 (CSB/UC1), U2.29 (SCK/UC2), U2.31 (VSSD), U2.33 (XSEL), U2.41 (PAD), U3.4 (GND), U3.9 (PAD), Y2.2, Y2.4, Y3.2, Y3.4
unnamed: C1.2, U1.35 (PB14), Y1.1
unnamed: C2.2, U1.36 (PB15), Y1.2
unnamed: C3.1, U1.41 (DECOUPLE)
unnamed: C4.1, U1.11 (HFXTAL_P), Y2.1
unnamed: C5.1, U1.10 (HFXTAL_N), Y2.3
unnamed: C6.1, U2.34 (XTAL2), Y3.3
unnamed: C7.1, U2.35 (XTAL1), Y3.1
unnamed: C11.1, U2.9 (VFILT), U2.16 (VIN)
unnamed: C12.1, U2.10 (V20V)
unnamed: C13.1, U2.5 (CAV)
unnamed: C14.1, U2.8 (CEQ2)
unnamed: C14.2, U2.7 (CEQ1)
unnamed: C15.2, U2.4 (CCP)
unnamed: D1.2 (A), R1.2
unnamed: D2.2 (A), D3.2 (A2), J3.P+ (+)
unnamed: D4.1 (A1), J1.3, R11.2
unnamed: D5.1 (A1), J1.2, R10.2
unnamed: D6.1 (A1), J2.7, R9.2
unnamed: D7.1 (A1), J2.6, R8.2
unnamed: D8.1 (A1), J2.5, R7.2
unnamed: D9.1 (A1), J2.4, R6.2
unnamed: D10.1 (A1), J2.3, R5.2
unnamed: D11.1 (A1), J2.2, R4.2
unnamed: L1.1, R3.2, U2.20 (VDD1M)
unnamed: L1.2, U2.17 (VSW1)
unnamed: R2.2, U2.3 (TXO)
unnamed: R12.2, U2.37 (RESETB)
unnamed: R13.2, U2.38 (FANIN)
unnamed: TP2.1, U1.26 (PA1)
unnamed: TP3.1, U1.25 (PA0)

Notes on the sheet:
Power Flags
KNX Transceiver
I2C Connector
Debug Header
Net Ties
GPIO Connector
Microcontroller
Button and LED
KNX Connector
Flash Chip

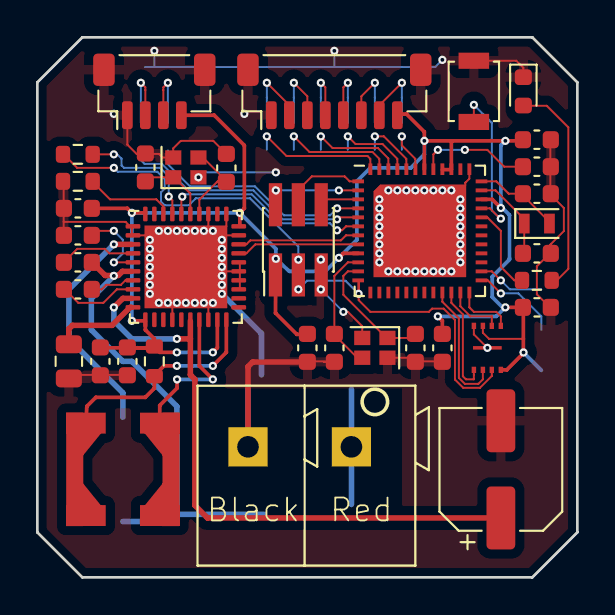
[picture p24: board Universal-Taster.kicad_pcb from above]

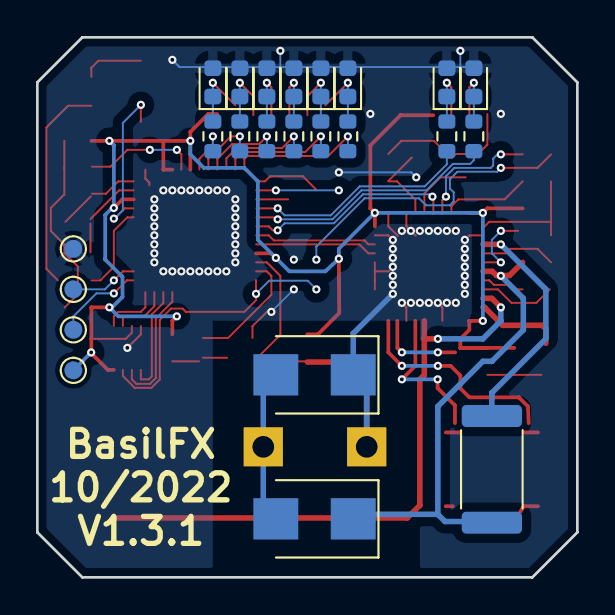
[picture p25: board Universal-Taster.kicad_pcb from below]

Board: 2 copper layers, 30.0 x 30.0 mm, 59 parts (23 on the bottom side), 54 nets.

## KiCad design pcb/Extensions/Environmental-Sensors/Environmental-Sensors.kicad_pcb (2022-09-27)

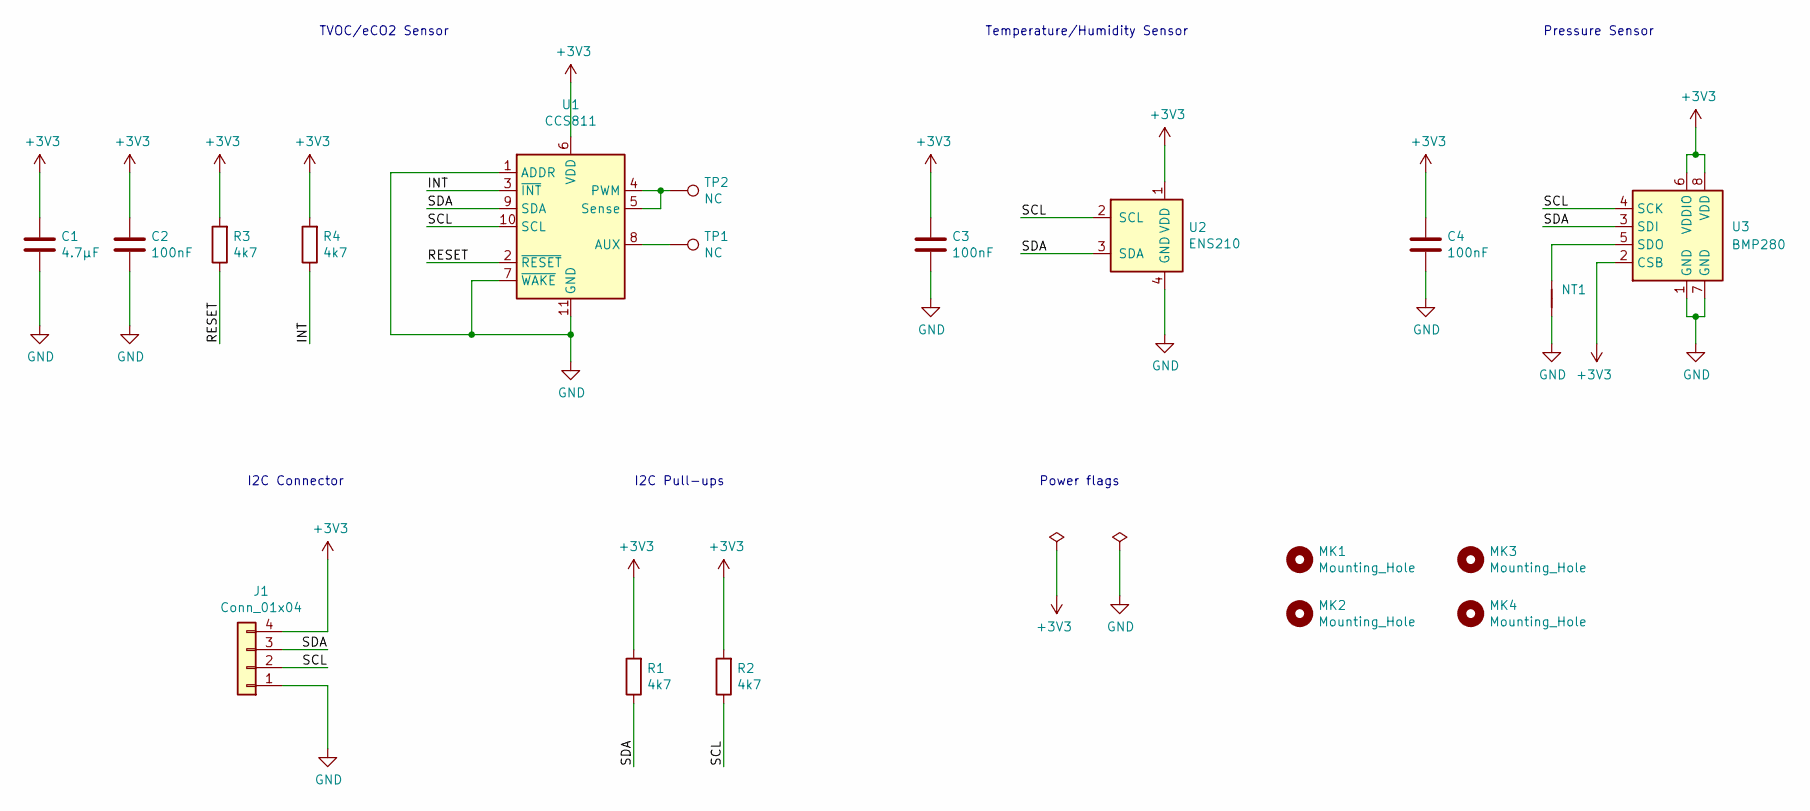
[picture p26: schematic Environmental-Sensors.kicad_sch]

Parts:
C1: 4.7µF; C_0402_1005Metric
C2, C3, C4: 100nF; C_0402_1005Metric
J1: Conn_01x04; PinHeader_1x04_P1.27mm_Vertical
MK1, MK2, MK3, MK4: Mounting_Hole; TestPoint_Plated_Hole_D2.0mm
NT1: NetTie_2; NetTie-2_SMD_Pad0.25mm
R1, R2, R3, R4: 4k7; R_0402_1005Metric
TP1, TP2: NC; TestPoint_Pad_D1.0mm
U1: CCS811; AMS_LGA-10-1EP_2.7x4mm_P0.6mm
U2: ENS210; AMS_QFN-4-1EP_2x2mm_P0.95mm_EP0.7x1.6mm
U3: BMP280; Bosch_LGA-8_2x2.5mm_P0.65mm_ClockwisePinNumbering; MPN BMP280

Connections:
+3V3: C1.1, C2.1, C3.1, C4.1, J1.4, R1.2, R2.2, R3.2, R4.2, U1.6 (VDD), U2.1 (VDD), U3.2 (CSB), U3.6 (VDDIO), U3.8 (VDD)
/INT: R4.1, U1.3 (~INT)
/RESET: R3.1, U1.2 (~RESET)
/SCL: J1.2, R2.1, U1.10 (SCL), U2.2 (SCL), U3.4 (SCK)
/SDA: J1.3, R1.1, U1.9 (SDA), U2.3 (SDA), U3.3 (SDI)
GND: C1.2, C2.2, C3.2, C4.2, J1.1, NT1.1, U1.1 (ADDR), U1.7 (~WAKE), U1.11 (GND), U2.4 (GND), U2.5 (GND), U3.1 (GND), U3.7 (GND)
unnamed: NT1.2, U3.5 (SDO)
unnamed: TP1.1, U1.8 (AUX)
unnamed: TP2.1, U1.4 (PWM), U1.5 (Sense)

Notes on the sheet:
TVOC/eCO2 Sensor
Power flags
Temperature/Humidity Sensor
I2C Connector
Pressure Sensor
I2C Pull-ups

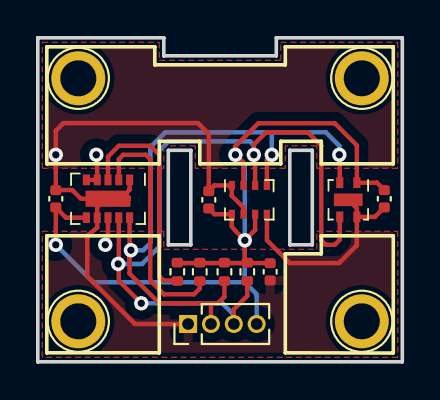
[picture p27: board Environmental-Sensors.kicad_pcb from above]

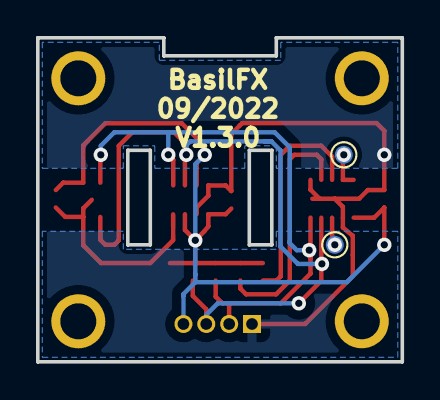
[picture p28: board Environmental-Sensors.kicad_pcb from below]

Board: 2 copper layers, 20.2 x 18.0 mm, 19 parts (2 on the bottom side), 9 nets.

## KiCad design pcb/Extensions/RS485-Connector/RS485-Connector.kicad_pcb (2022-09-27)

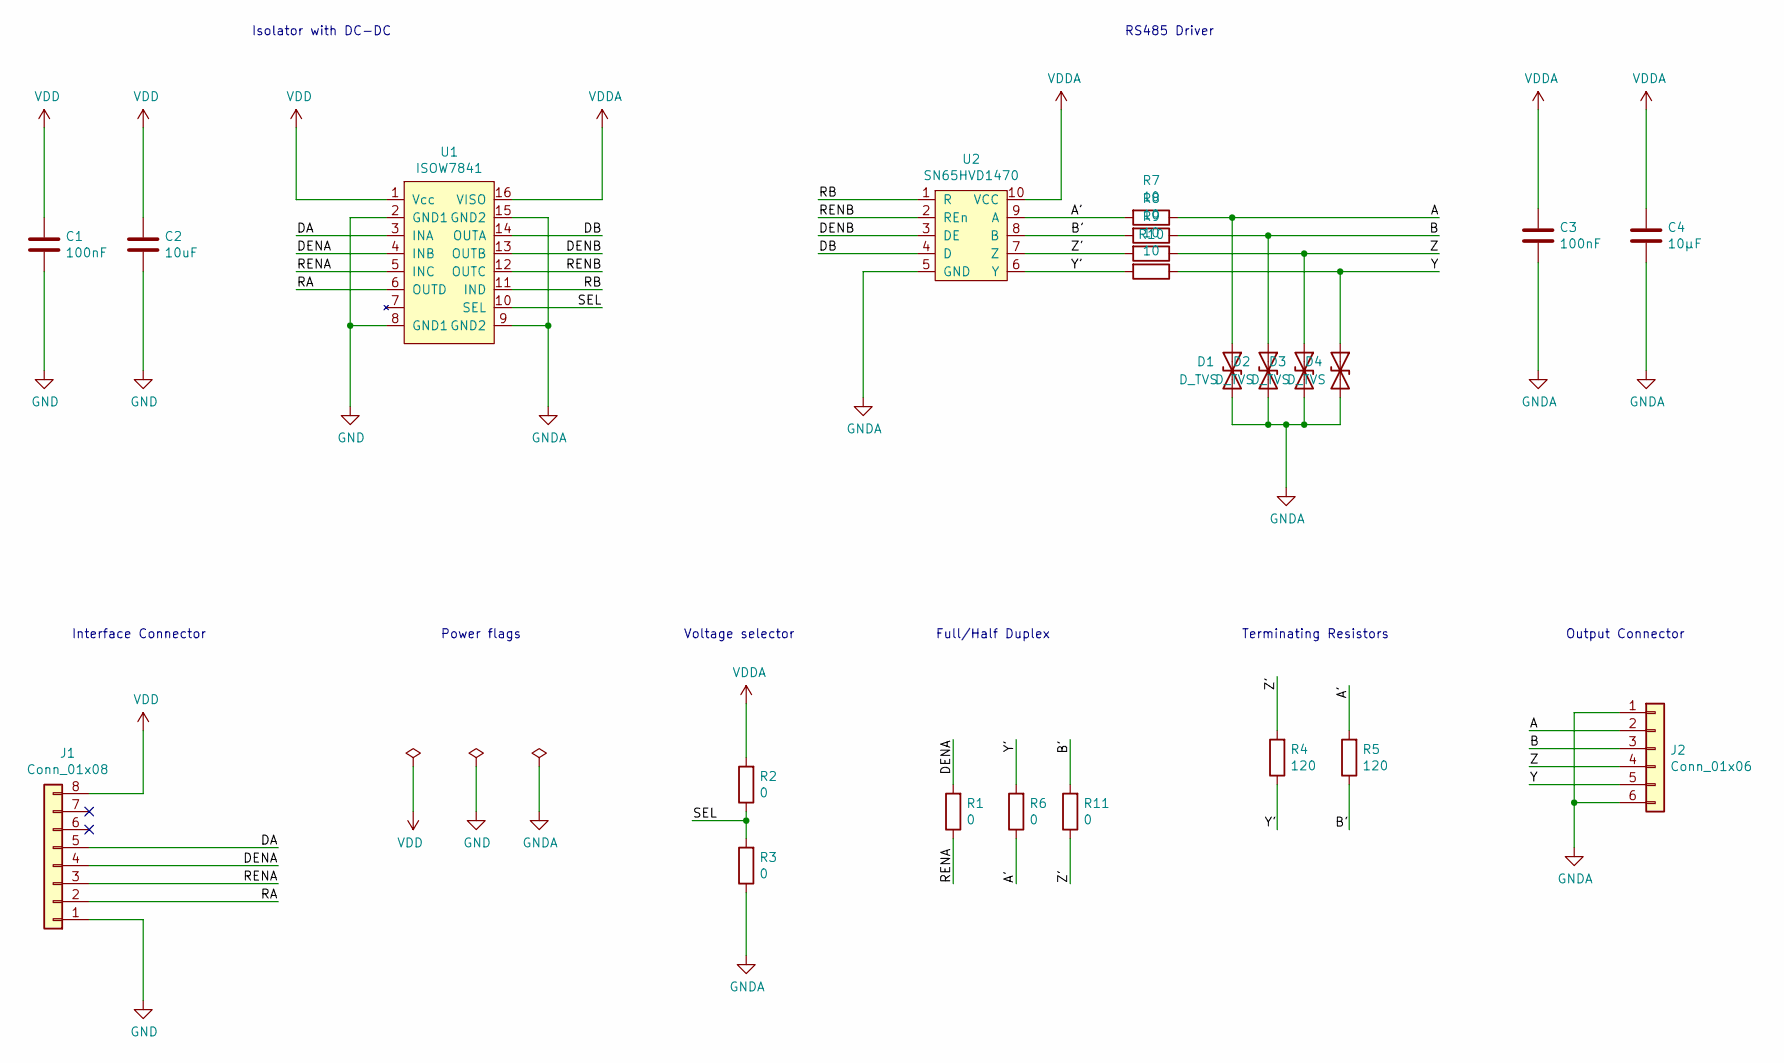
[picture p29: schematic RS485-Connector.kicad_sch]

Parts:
C1, C3: 100nF; C_0603_1608Metric
C2: 10uF; C_0603_1608Metric
C4: 10µF; C_0603_1608Metric
D1, D2, D3, D4: D_TVS; D_0603_1608Metric
J1: Conn_01x08; PinHeader_1x08_P1.27mm_Vertical
J2: Conn_01x06; TerminalBlock_TE_282834-6_1x06_P2.54mm_Horizontal
R1, R2, R3, R6, R11: 0; R_0603_1608Metric
R4, R5: 120; R_0603_1608Metric
R7, R8, R9, R10: 10; R_0603_1608Metric
U1: ISOW7841; SOIC-16W_7.5x10.3mm_P1.27mm
U2: SN65HVD1470; MSOP-10_3x3mm_P0.5mm

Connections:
/A: D1.1 (A1), J2.2, R7.1
/A': R5.2, R6.1, R7.2, U2.9 (A)
/B: D2.1 (A1), J2.3, R8.1
/B': R5.1, R8.2, R11.2, U2.8 (B)
/DA: J1.5, U1.3 (INA)
/DB: U1.14 (OUTA), U2.4 (D)
/DENA: J1.4, R1.2, U1.4 (INB)
/DENB: U1.13 (OUTB), U2.3 (DE)
/RA: J1.2, U1.6 (OUTD)
/RB: U1.11 (IND), U2.1 (R)
/RENA: J1.3, R1.1, U1.5 (INC)
/RENB: U1.12 (OUTC), U2.2 (REn)
/SEL: R2.1, R3.2, U1.10 (SEL)
/Y: D4.1 (A1), J2.5, R10.1
/Y': R4.1, R6.2, R10.2, U2.6 (Y)
/Z: D3.1 (A1), J2.4, R9.1
/Z': R4.2, R9.2, R11.1, U2.7 (Z)
GND: C1.2, C2.2, J1.1, U1.2 (GND1), U1.8 (GND1)
GNDA: C3.2, C4.2, D1.2 (A2), D2.2 (A2), D3.2 (A2), D4.2 (A2), J2.1, J2.6, R3.1, U1.9 (GND2), U1.15 (GND2), U2.5 (GND)
VDD: C1.1, C2.1, J1.8, U1.1 (Vcc)
VDDA: C3.1, C4.1, R2.2, U1.16 (VISO), U2.10 (VCC)

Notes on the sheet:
Terminating Resistors
RS485 Driver
Interface Connector
Power flags
Output Connector
Voltage selector
Isolator with DC-DC
Full/Half Duplex

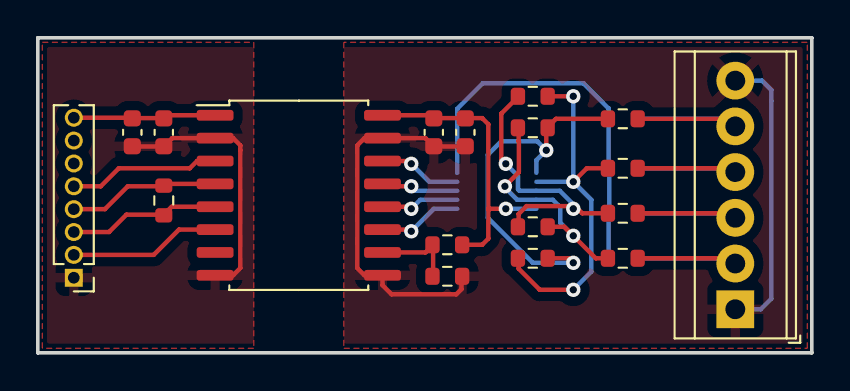
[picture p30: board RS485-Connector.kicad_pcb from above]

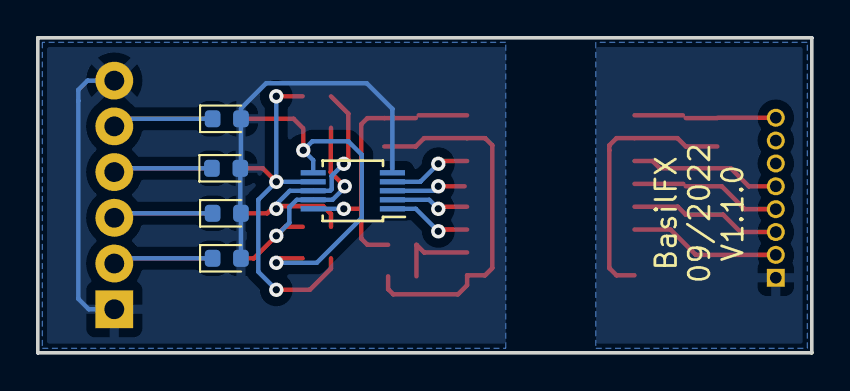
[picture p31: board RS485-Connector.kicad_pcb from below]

Board: 2 copper layers, 43.0 x 17.5 mm, 23 parts (5 on the bottom side), 21 nets.

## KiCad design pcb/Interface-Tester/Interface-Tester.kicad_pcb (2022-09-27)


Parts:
D1, D2, D3, D4, D5, D6: LED; LED_0603_1608Metric
J1: INTERFACE; PinHeader_1x08_P2.54mm_Vertical
J2: I2C; PinHeader_1x04_P2.54mm_Vertical
J3: PWR; PinHeader_1x03_P2.54mm_Vertical
SW1, SW2, SW3, SW4, SW5, SW6, SW7, SW8: SW; SW_PUSH_6mm

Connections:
+3V3: J1.8, J2.4, J3.3
/IF0: D1.2 (A), J1.2, SW3.1
/IF1: D2.2 (A), J1.3, SW4.1
/IF2: D3.2 (A), J1.4, SW5.1
/IF3: D4.2 (A), J1.5, SW6.1
/IF4: D5.2 (A), J1.6, SW7.1
/IF5: D6.2 (A), J1.7, SW8.1
/RAIL: D1.1 (K), D2.1 (K), D3.1 (K), D4.1 (K), D5.1 (K), D6.1 (K), J3.2, SW1.2, SW2.2, SW3.2, SW4.2, SW5.2, SW6.2, SW7.2, SW8.2
/SCL: J2.2, SW1.1
/SDA: J2.3, SW2.1
GND: J1.1, J2.1, J3.1

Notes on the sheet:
Voltage Selector
GPIO
Power Flags
I2C


Board: 2 copper layers, 62.8 x 18.5 mm, 17 parts (0 on the bottom side), 11 nets.

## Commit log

2018-08-13 Add taster
    [Taster.kicad_pcb, Taster.sch]
2018-08-13 Add sensors.
    [Sensors.kicad_pcb, Sensors.sch]
2018-08-13 Add interface tester.
    [Interface-Tester.kicad_pcb, Interface-Tester.sch]
2018-08-13 Version 1.1.0 of the Taster board.
    [Taster.kicad_pcb, Taster.sch]
2018-08-20 Version 1.2.0 of board
    [Taster.kicad_pcb, Taster.sch]
2018-08-20 Version 1.1.0 of interface tester.
    [Interface-Tester.kicad_pcb, Interface-Tester.sch]
2018-08-21 Move and rename Sensors to Environmental-Sensors.
    [Environmental-Sensors.kicad_pcb, Environmental-Sensors.sch]
2018-08-21 Added board v1.1.0 of environmental sensors
    [Environmental-Sensors.kicad_pcb, Environmental-Sensors.sch]
2018-08-22 Added version 1.2.0 of environmental sensors board.
    [Environmental-Sensors.kicad_pcb, Environmental-Sensors.sch]
2018-08-26 Add DSMR Connector v1.0.0
    [DSMR-Connector.kicad_pcb, DSMR-Connector.sch]
2018-08-26 Add RS-485 module version 1.0.0
    [RS485-Connector.kicad_pcb, RS485-Connector.sch]
2021-01-25 Restructure repository.
    [DSMR-Connector.kicad_pcb, DSMR-Connector.sch, Environmental-Sensors.kicad_pcb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]
2021-01-25 Add images of soldered boards.
2021-01-25 Add enclosure.
    [Bottom.stl, Top.stl]
2021-07-15 Version 1.2.1 of Universal-Taster
    - More clearance of traces around resistor SCL line
    - Fixed DRC errors (new in Kicad 5.1.x)
    [Taster.kicad_pcb]
2021-07-15 Updated DSMR-Connector after first tests.
    [DSMR-Connector.sch]
2021-07-15 DSMR-Connector v1.1.0
    - Add missing pull-up resistor
    - Add signal inverter.
    [DSMR-Connector.kicad_pcb]
2022-09-14 Fix (and convert) hardcoded path to 3D model
    [Taster.kicad_pcb]
2022-09-27 Upgrade Universal Taster to KiCad 6.0
    [BM04B-SRSS-TB.step, BM08B-SRSS-TB.step, SRR5028.step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]
2022-09-27 Upgrade Interface Tester to KiCad 6.0
    [Interface-Tester.kicad_pcb, Interface-Tester.kicad_sch, Interface-Tester.sch]
2022-09-27 Upgrade RS485 Connector to KiCad 6.0
    [RS485-Connector.kicad_pcb, RS485-Connector.kicad_sch, RS485-Connector.sch]
2022-09-27 Upgrade Environmental Sensors to KiCad 6.0
    [Environmental-Sensors.kicad_pcb, Environmental-Sensors.kicad_sch, Environmental-Sensors.sch]
2022-09-27 Upgrade DSMR Connector to KiCad 6.0
    [Amphenol-54601-906WPLF.step, DSMR-Connector.kicad_pcb, DSMR-Connector.kicad_sch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]
2022-09-27 Properly rename Taster to Universal-Taster
    [Universal-Taster.kicad_pcb, Universal-Taster.kicad_sch]
2022-10-03 Fix universal taster
    [Universal-Taster.kicad_pcb]
2022-10-03 Add GitHub action to publish interactive BoM
2022-10-03 Add interactive BoM to Universal Taster
    [Universal-Taster.kicad_pcb, Universal-Taster.kicad_sch]
2022-10-03 Add interactive BoM to Interface Tester
2022-10-03 Add interactive BoM to RS485 Connector
2022-10-03 Add interactive BoM to Environmental Sensors
2022-10-03 Add interactive BoM to DSMR Connector
    [DSMR-Connector.kicad_pcb, DSMR-Connector.kicad_sch]
2022-10-03 Add Tracespace board render settings
2022-10-03 Replace 3D pictures with 2D images for DSMR Connector
2022-10-03 Replace 3D pictures with 2D images for Environmental Sensors
2022-10-03 Replace 3D pictures with 2D images for RS485 Connector
2025-01-06 Add firmware v0.4.0
    The slot0.4.bin and slot1.4.bin are update files.
